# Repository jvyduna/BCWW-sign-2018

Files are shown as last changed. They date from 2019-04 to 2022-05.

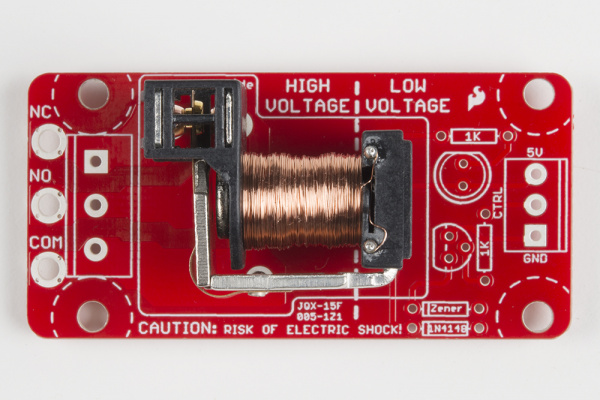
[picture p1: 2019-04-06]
Physical sign design/Microcontroller/RelayNaked.jpg

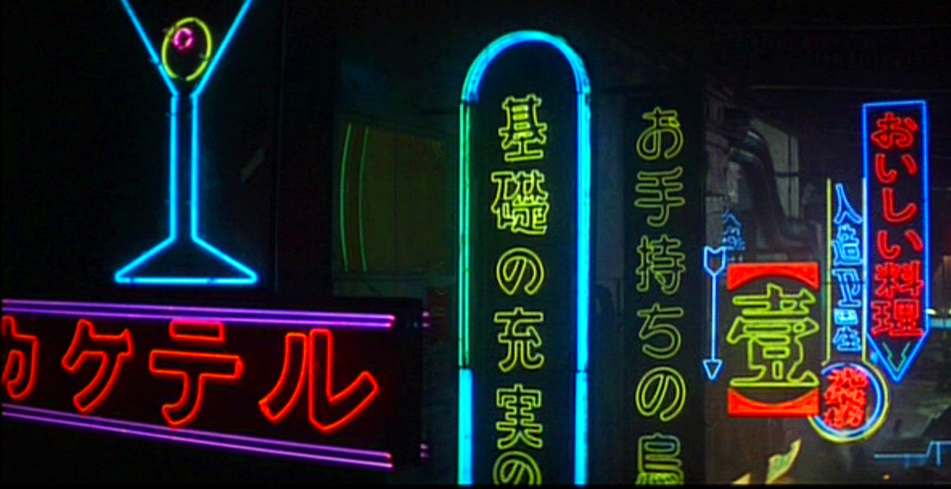
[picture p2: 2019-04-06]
Physical sign design/Inspiration board/Neon row.jpg

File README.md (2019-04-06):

# Bao Chicka Wow Wow blinking sign

BCWW Sign at dusk

[Video of sign at Burning Man 2018 and fab process](https://vimeo.com/292647048)

## Files

The contents of this repo mirror the structure of the Arduino project directory. Dependencies are included in the libraries/ folder. For the time-of-day mode switching timers to work, you'll need to copy the contents of this directory into your Arduino build location for libraries. That's usually just ```{your Arduino homedir}/libraries```.

## Hardware

Arduino Pro or Pro Mini (config included)
ATMega328P (5V, 16 MHz)

## Pinout

Documented in the code

All 5 signs are connectted in parallel on a 10-conductor ribbon cable.
One line controls the servo that changes the fourth sign from  WOW to NOW

## Physical sign design files

Design (Illustrator)

Modeling / CAD (Autodesk Inventor)

CNC GCode: Vector / ShopBot

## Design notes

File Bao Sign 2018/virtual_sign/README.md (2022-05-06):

Runs a virtual version of the sign in your terminal.

To build and run, run `build_and_run.sh`

If you want to see the debug logs, run `tail -F /tmp/virtual_sign.err`

To switch to Hot Bao Now mode, `touch /tmp/bao.touch`

To switch back, `rm /tmp/bao.touch`

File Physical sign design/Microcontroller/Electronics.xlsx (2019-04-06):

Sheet: BOM
Description | Need | Bought
Ribbon Cable | 50' | 100' | https://smile.amazon.com/Pc-Accessories-1-27mm-Connectors-Conductors/dp/B00JKE10UQ
Ribbon snap-on Fem | 6 | 50 | https://smile.amazon.com/gp/product/B00DE5CTMK/ref=ox_sc_act_title_1?smid=A64W1E1ZZHST0&psc=1
Ribbon male box header | 5 | 6 | https://www.sparkfun.com/products/8506
Protoboard |  |  | https://www.sparkfun.com/products/13268
NC Relay, Zener, Diode, 1KOhm, 293904 | 5 | 7 | https://cdn.sparkfun.com/datasheets/Components/General/SparkFun_Beefcake_Relay_Control_Kit_v20a.pdf
Servo for N/W | 1 | 1 | https://www.sparkfun.com/products/11965
5V 5A Power Supply - host in N/W
Arduino Pro Mini 5V

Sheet: Ribbon Pinout
 |  |  | Viewed from front of male connector
Pin | Function
1 | GND
2 | GND2 or SIGN1OUTLINE
3 | SIGN1 |  |  | (Relay)
4 | SIGN2
5 | SIGN3 |  |  | NOTCH
6 | SIGN4 | 9 | 7 | 5 | 3 | 1
7 | SIGN5 | 10 | 8 | 6 | 4 | 2
8 | SIGN4SERVO
9 | Vcc2 or SIGN5OUTLINE
10 | Vcc (from Sign4)
 |  |  |  | NOTCH
 |  | Vcc2 or SIGN5OUTLINE | SIGN5 | SIGN3 | SIGN1 | GND
 |  | Vcc (from Sign4) | SIGN4SERVO | SIGN4 | SIGN2 | GND2 or SIGN1OUTLINE

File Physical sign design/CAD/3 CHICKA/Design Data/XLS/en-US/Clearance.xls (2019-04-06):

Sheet: Ansi Unified Screw Threads
I | Sort Order -1
Fastener Type | Size | Shaft Diameters |  |  | Head Dimensions
 |  | Close | Normal | Loose | Diameter | Depth/Angle | Head Type
Flat Head Machine Screw (82) | #0 | 0.0635 | 0.07 | 0.073 | 0.119 | 82 | 2
Flat Head Machine Screw (82) | #1 | 0.076 | 0.081 | 0.089 | 0.146 | 82 | 2
Flat Head Machine Screw (82) | #2 | 0.089 | 0.096 | 0.1065 | 0.172 | 82 | 2
Flat Head Machine Screw (82) | #3 | 0.104 | 0.11 | 0.12 | 0.199 | 82 | 2
Flat Head Machine Screw (82) | #4 | 0.116 | 0.1285 | 0.136 | 0.225 | 82 | 2
Flat Head Machine Screw (82) | #5 | 0.1285 | 0.136 | 0.154 | 0.252 | 82 | 2
Flat Head Machine Screw (82) | #6 | 0.144 | 0.1495 | 0.1695 | 0.279 | 82 | 2
Flat Head Machine Screw (82) | #8 | 0.1695 | 0.177 | 0.1935 | 0.332 | 82 | 2
Flat Head Machine Screw (82) | #10 | 0.196 | 0.201 | 0.221 | 0.385 | 82 | 2
Flat Head Machine Screw (82) | #12 | 0.221 | 0.228 | 0.246 | 0.438 | 82 | 2
Flat Head Machine Screw (82) | 1/4 | 0.257 | 0.266 | 0.2812 | 0.507 | 82 | 2
Flat Head Machine Screw (82) | 5/16 | 0.323 | 0.332 | 0.3437 | 0.635 | 82 | 2
Flat Head Machine Screw (82) | 3/8 | 0.386 | 0.397 | 0.4062 | 0.762 | 82 | 2
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

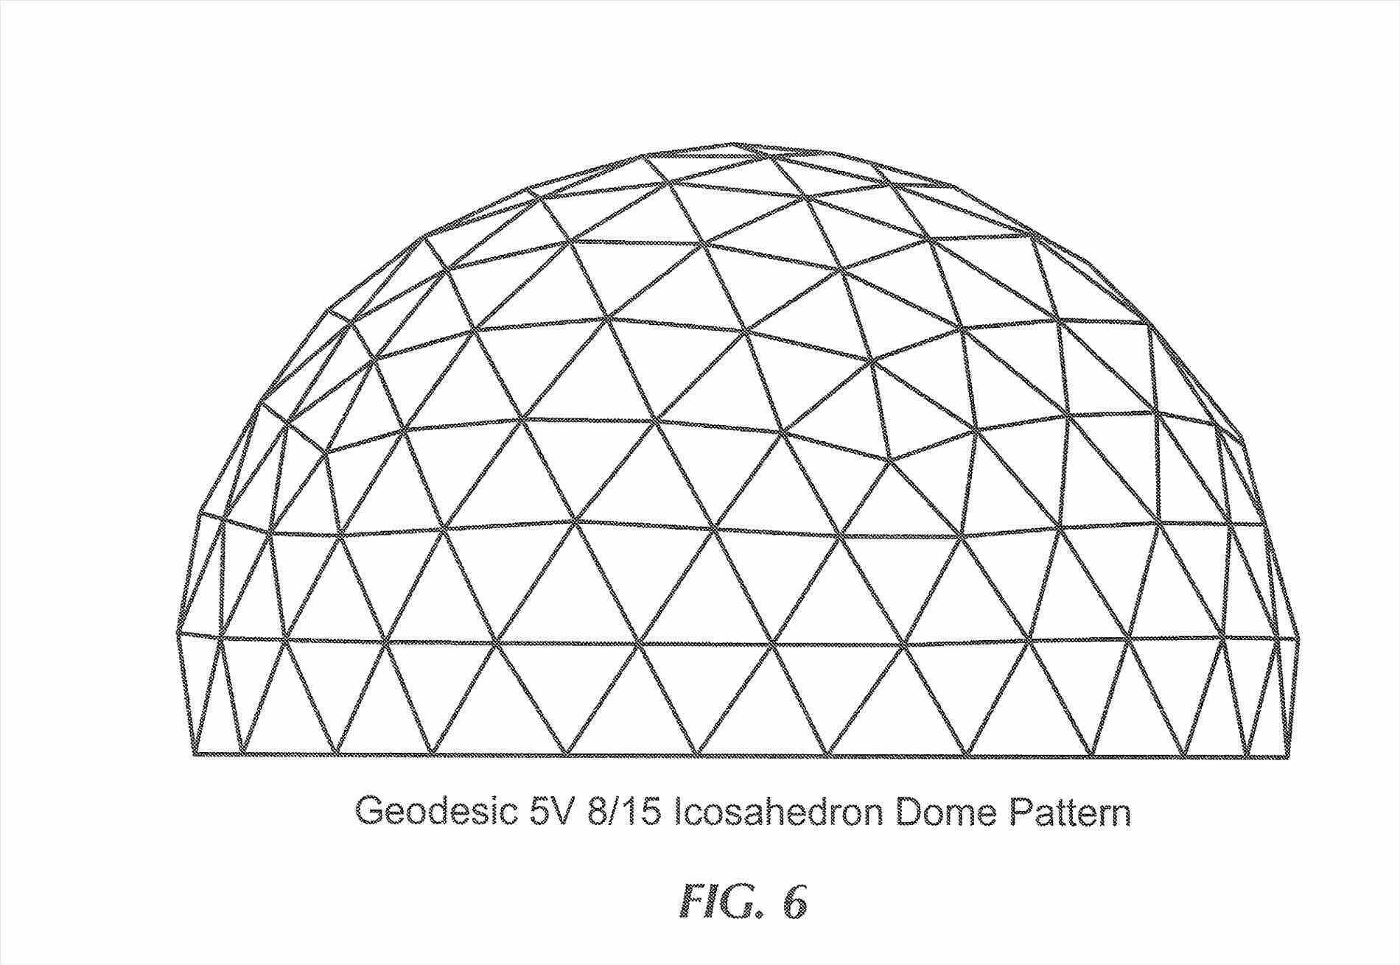
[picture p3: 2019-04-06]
Physical sign design/Assets/dome-drawing-the-in-architecturerhthoughtcocom-gallery-of-tejlgaard-u-jepsen-transform-a-temporary-rharchdailycom-gallery-geodesic-dome-drawing-of-tejlgaard-u-jepsen-trans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

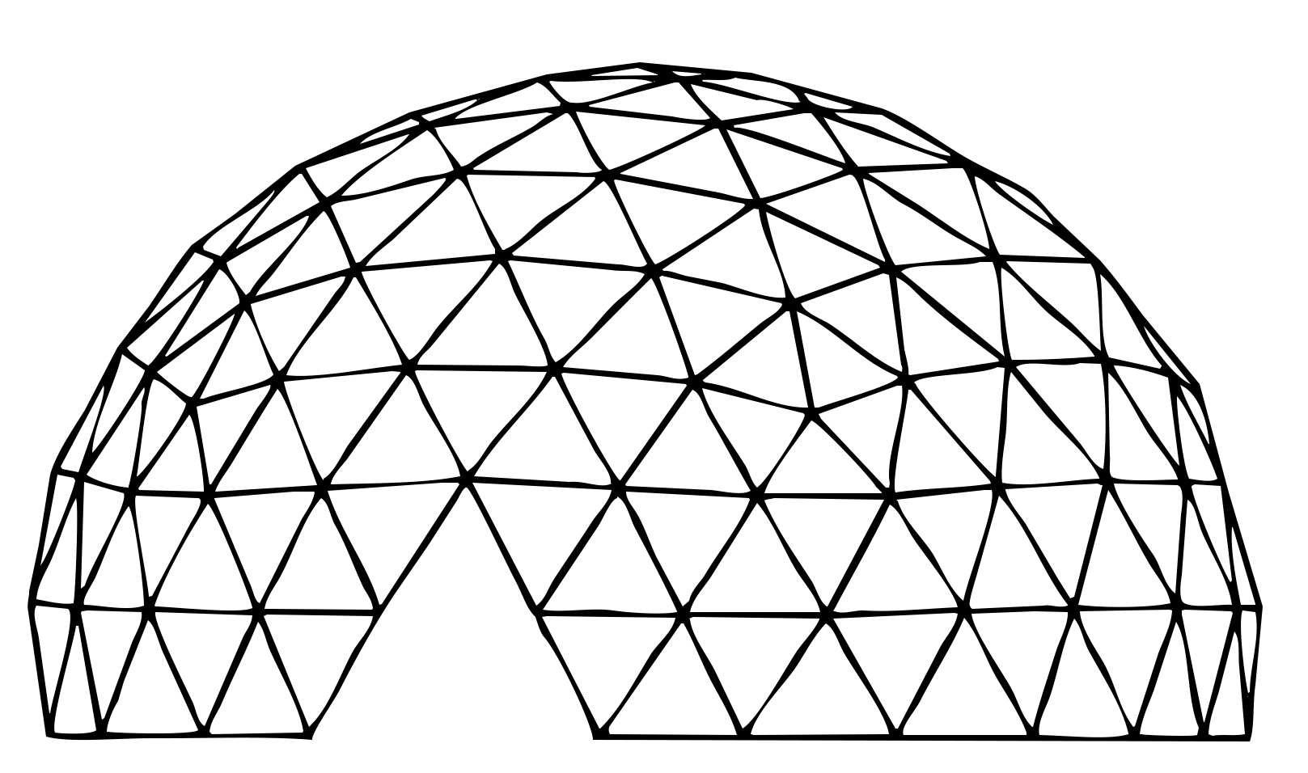
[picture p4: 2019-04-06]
Physical sign design/Assets/blackdome on tx.png

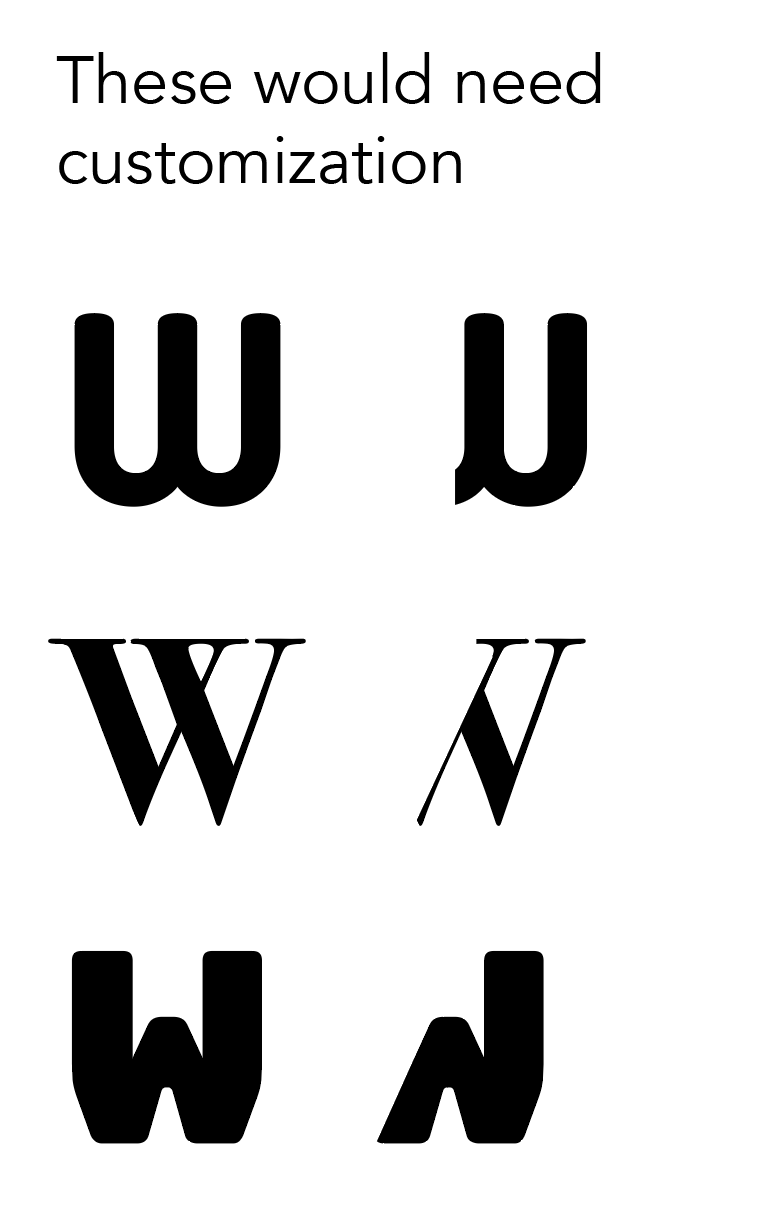
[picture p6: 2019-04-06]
Physical sign design/Prototypes/W-N not so much.png

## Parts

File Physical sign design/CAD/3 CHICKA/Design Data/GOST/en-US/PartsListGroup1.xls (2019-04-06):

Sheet: Лист 1
Инв. № подл |  |  |  | Подп. и дата | Взам. инв. № | Инв. № дубл. |  |  | Подп. и дата
Формат | Зона | Поз. | Обозначение |  |  |  | Наименование |  |  |  |  |  | Кол. на исполнение
 |  |  |  |  |  |  |  |  |  |  |  | Лит.
 |  |  |  |  |  |  |  |  |  |  |  | Код
 |  |  |  |  |  |  |  | Изм. | Лист | № докум | Подпись |  | Дата
 |  |  |  |  |  |  |  | Разраб.
 |  |  |  |  |  |  |  | Пров.
 |  |  |  |  |  |  |  | Н.контр
 |  |  |  |  |  |  |  | Утв.
 |  |  |  |  |  |  |  |  |  |  |  |  |  | Копировал

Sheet: Лист 2
Инв. № подл |  |  |  | Подп. и дата | Взам. инв. № | Инв. № дубл. |  |  | Подп. и дата
Формат | Зона | Поз. | Обозначение |  |  |  | Наименование |  |  |  |  | Кол. на исполнение
 |  |  |  |  |  |  |  | Изм. | Лист | № докум. | Подп. | Дата
 |  |  |  |  |  |  |  |  |  |  |  |  | Копировал
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

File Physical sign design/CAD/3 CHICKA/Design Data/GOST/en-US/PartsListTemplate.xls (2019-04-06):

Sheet: Лист 1
 | Формат | Зона |  | Поз. |  | Обозначение |  |  |  | Наименование |  |  |  | Кол. | Приме-чание
Подп. и дата
Инв. № дубл.
Взам. инв. №
Подп. и дата
 | Изм. |  | Лист |  | № докум |  | Подпись | Дата
Инв. № подл | Разраб. |  |  |  |  |  |  |  |  |  | Литера |  | Лист |  |  | Листов
 | Пров.
 | Н.контр
 | Утв.
 |  |  |  |  |  |  |  |  | Копировал |  |  | Формат А4

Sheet: Лист 2
 | Формат | Зона |  | Поз. |  | Обозначение |  |  |  | Наименование |  | Кол. | Приме-чание
Подп. и дата
Инв. № дубл.
Взам. инв. №
Подп. и дата
Инв. № подл
 | Изм. |  | Лист |  | № докум. |  | Подп. |  | Дата
 |  |  |  |  |  |  |  | Копировал |  |  | Формат А4
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

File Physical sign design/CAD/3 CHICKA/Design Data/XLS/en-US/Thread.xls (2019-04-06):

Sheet: ANSI Unified Screw Threads
I Q | ANSI Unified Screw Threads |  | Sort Order -1 |  | External |  |  |  |  |  |  | Internal
 |  |  |  |  |  | Major Dia |  | Pitch Dia |  | Minor Dia |  |  | Minor Dia |  | Pitch Dia |  | Major Dia |  | Tap Drill
Size | Size Suffix | Thread Designation | Custom Thread Designation | TPI | Class | Max | Min | Max | Min | Max | Min | Class | Min | Max | Min | Max | Min | Max | Basic
0.0118 |  | 30-318 UNM | 30-318 UNM | 318 | 2A | 0.0118 | 0.0112 | 0.0098 | 0.0092 | 0.0080 |  | 2B | 0.0085 | 0.0100 | 0.0098 | 0.0103 | 0.0120 |  | 0.0083
0.0138 |  | 35-282 UNM | 35-282 UNM | 282 | 2A | 0.0138 | 0.0131 | 0.0115 | 0.0109 | 0.0095 |  | 2B | 0.0101 | 0.0117 | 0.0115 | 0.0121 | 0.0140 |  | 0.0096
0.0157 |  | 40-254 UNM | 40-254 UNM | 254 | 2A | 0.0157 | 0.0150 | 0.0132 | 0.0126 | 0.0110 |  | 2B | 0.0117 | 0.0134 | 0.0132 | 0.0138 | 0.0160 |  | 0.0110
0.0177 |  | 45-254 UNM | 45-254 UNM | 254 | 2A | 0.0177 | 0.0170 | 0.0152 | 0.0145 | 0.0130 |  | 2B | 0.0136 | 0.0154 | 0.0152 | 0.0158 | 0.0180 |  | 0.0124
0.0197 |  | 50-203 UNM | 50-203 UNM | 203 | 2A | 0.0197 | 0.0189 | 0.0165 | 0.0158 | 0.0138 |  | 2B | 0.0146 | 0.0166 | 0.0165 | 0.0172 | 0.0200 |  | 0.0138
0.021 |  | 0000-160 NS | 0000-160 NS | 160 | 2A | 0.021 | 0.0195 | 0.0169 | 0.0158 | 0.0128 |  | 2B | 0.0169 | 0.0181 | 0.0169 | 0.0181 | 0.021
0.0217 |  | 55-203 UNM | 55-203 UNM | 203 | 2A | 0.0217 | 0.0208 | 0.0185 | 0.0178 | 0.0157 |  | 2B | 0.0165 | 0.0186 | 0.0185 | 0.0192 | 0.0220 |  | 0.0150
0.0236 |  | 60-169 UNM | 60-169 UNM | 169 | 2A | 0.0236 | 0.0227 | 0.0198 | 0.0190 | 0.0165 |  | 2B | 0.0175 | 0.0198 | 0.0198 | 0.0206 | 0.0241 |  | 0.0165

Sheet: Inch Tapping Threads
I Q X | Inch Tapping Threads |  | Sort Order - 5 |  | External |  |  |  |  |  |  | Internal
 |  |  |  |  |  | Major Dia |  | Pitch Dia |  | Minor Dia |  |  | Minor Dia |  | Pitch Dia |  | Major Dia |  | Tap Drill
Size | Size Suffix | Thread Designation | Custom Thread Designation | TPI | Class | Max | Min | Max | Min | Max | Min | Class | Min | Max | Min | Max | Min | Max | Basic
0.0600 |  | 0-48 | 0-48 | 48 | 2B | 0.0600 | 0.0540 | 0.0480 | 0.0435 | 0.0360 | 0.0330
0.0730 |  | 1-42 | 1-42 | 42 | 2B | 0.0750 | 0.0690 | 0.0620 | 0.0575 | 0.0490 | 0.0460
0.0860 |  | 2-32 | 2-32 | 32 | 2B | 0.0880 | 0.0820 | 0.0760 | 0.0710 | 0.0640 | 0.0600
0.0990 |  | 3-28 | 3-28 | 28 | 2B | 0.1010 | 0.0950 | 0.0880 | 0.0830 | 0.0750 | 0.0710
0.1120 |  | 4-24 | 4-24 | 24 | 2B | 0.1140 | 0.1080 | 0.1000 | 0.0950 | 0.0860 | 0.0820
0.1250 |  | 5-20 | 5-20 | 20 | 2B | 0.1300 | 0.1230 | 0.1120 | 0.1065 | 0.0940 | 0.0900
0.1380 |  | 6-20 | 6-20 | 20 | 2B | 0.1390 | 0.1320 | 0.1215 | 0.1155 | 0.1040 | 0.0990
0.1510 |  | 7-19 | 7-19 | 19 | 2B | 0.1540 | 0.1470 | 0.1345 | 0.1280 | 0.1150 | 0.1090
0.1640 |  | 8-18 | 8-18 | 18 | 2B | 0.1660 | 0.1590 | 0.1440 | 0.1375 | 0.1220 | 0.1160
0.1900 |  | 10-16 | 10-16 | 16 | 2B | 0.1890 | 0.1820 | 0.1650 | 0.1585 | 0.1410 | 0.1350
0.2160 |  | 12-14 | 12-14 | 14 | 2B | 0.2150 | 0.2080 | 0.1895 | 0.1825 | 0.1640 | 0.1570
0.2420 |  | 14-14 | 14-14 | 14 | 2B | 0.2410 | 0.2340 | 0.2130 | 0.2060 | 0.1850 | 0.1780
0.2500 |  | 1/4-14 | 1/4-14 | 14 | 2B | 0.2460 | 0.2370 | 0.2190 | 0.2110 | 0.1920 | 0.1850
0.3125 |  | 5/16-12 | 5/16-12 | 12 | 2B | 0.3150 | 0.3060 | 0.2795 | 0.2710 | 0.2440 | 0.2360
0.3750 |  | 3/8-12 | 3/8-12 | 12 | 2B | 0.3800 | 0.3710 | 0.3445 | 0.3350 | 0.3090 | 0.2990
0.4375 |  | 7/16-10 | 7/16-10 | 10 | 2B | 0.4400 | 0.4290 | 0.3995 | 0.3890 | 0.3590 | 0.3490
0.5000 |  | 1/2-10 | 1/2-10 | 10 | 2B | 0.5040 | 0.4930 | 0.4635 | 0.4530 | 0.4230 | 0.4130

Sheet: Metric Forming Screw Threads
M P X | Metric Forming Screw Threads |  | Sort Order - 6 |  | External |  |  |  |  |  |  | Internal
 |  |  |  |  |  | Major Dia |  | Pitch Dia |  | Minor Dia |  |  | Minor Dia |  | Pitch Dia |  | Major Dia |  | Tap Drill
Size | Size Suffix | Thread Designation | Custom Thread Designation | Pitch | Class | Max | Min | Max | Min | Max | Min | Class | Min | Max | Min | Max | Min | Max | Basic
1.5 |  | 1.5x0.5 | 1.5x0.5 | 0.5 | 6g | 1.520 | 1.380 | 1.215 | 1.110 | 0.910 | 0.840
1.5 |  | ST1.5x0.5 | ST1.5x0.5 | 0.5 | 6g | 1.520 | 1.380 | 1.215 | 1.110 | 0.910 | 0.840
1.9 |  | 1.9x0.6 | 1.9x0.6 | 0.6 | 6g | 1.900 | 1.760 | 1.570 | 1.465 | 1.240 | 1.170
1.9 |  | ST1.9x0.6 | ST1.9x0.6 | 0.6 | 6g | 1.900 | 1.760 | 1.570 | 1.465 | 1.240 | 1.170
2.2 |  | 2.2x0.8 | 2.2x0.8 | 0.8 | 6g | 2.240 | 2.100 | 1.935 | 1.810 | 1.630 | 1.520
2.2 |  | ST2.2x0.8 | ST2.2x0.8 | 0.8 | 6g | 2.240 | 2.100 | 1.935 | 1.810 | 1.630 | 1.520
2.6 |  | 2.6x0.9 | 2.6x0.9 | 0.9 | 6g | 2.570 | 2.430 | 2.235 | 2.115 | 1.900 | 1.800
2.6 |  | ST2.6x0.9 | ST2.6x0.9 | 0.9 | 6g | 2.570 | 2.430 | 2.235 | 2.115 | 1.900 | 1.800
2.9 |  | 2.9x1 | 2.9x1 | 1 | 6g | 2.900 | 2.760 | 2.540 | 2.420 | 2.180 | 2.080
2.9 |  | 2.9x1.1 | 2.9x1.1 | 1.1 | 6g | 2.900 | 2.760 | 2.540 | 2.420 | 2.180 | 2.080
2.9 |  | ST2.9x1.1 | ST2.9x1.1 | 1.1 | 6g | 2.900 | 2.760 | 2.540 | 2.420 | 2.180 | 2.080
2.9 |  | 2.9x1.3 | 2.9x1.3 | 1.3 | 6g | 2.900 | 2.720 | 2.540 | 2.355 | 1.890 | 1.700
2.9 |  | 2.9x1.4 | 2.9x1.4 | 1.4 | 6g | 2.900 | 2.720 | 2.340 | 2.175 | 1.780 | 1.630
3.3 |  | 3.3x1.3 | 3.3x1.3 | 1.3 | 6g | 3.300 | 3.120 | 2.795 | 2.665 | 2.290 | 2.210
3.3 |  | ST3.3x1.3 | ST3.3x1.3 | 1.3 | 6g | 3.300 | 3.120 | 2.795 | 2.665 | 2.290 | 2.210
3.5 |  | 3.5x1.3 | 3.5x1.3 | 1.3 | 6g | 3.530 | 3.350 | 3.085 | 2.930 | 2.640 | 2.510
3.5 |  | ST3.5x1.3 | ST3.5x1.3 | 1.3 | 6g | 3.530 | 3.350 | 3.085 | 2.930 | 2.640 | 2.510
3.5 |  | 3.5x1.6 | 3.5x1.6 | 1.6 | 6g | 3.530 | 3.350 | 2.920 | 2.755 | 2.310 | 2.160
3.5 |  | 3.5x3.2 | 3.5x3.2 | 3.2 | 6g | 3.530 | 3.310 | 2.800 | 2.600 | 2.070 | 1.890
3.9 |  | 3.9x1.3 | 3.9x1.3 | 1.3 | 6g | 3.910 | 3.730 | 3.415 | 3.250 | 2.920 | 2.770
3.9 |  | ST3.9x1.3 | ST3.9x1.3 | 1.3 | 6g | 3.910 | 3.730 | 3.415 | 3.250 | 2.920 | 2.770
3.9 |  | 3.9x1.6 | 3.9x1.6 | 1.6 | 6g | 3.910 | 3.730 | 3.300 | 3.135 | 2.690 | 2.540
3.9 |  | 3.9x3.2 | 3.9x3.2 | 3.2 | 6g | 3.910 | 3.690 | 3.180 | 2.980 | 2.450 | 2.270
4.2 |  | 4.2x1.4 | 4.2x1.4 | 1.4 | 6g | 4.220 | 4.040 | 3.660 | 3.495 | 3.100 | 2.950
4.2 |  | ST4.2x1.4 | ST4.2x1.4 | 1.4 | 6g | 4.220 | 4.040 | 3.660 | 3.495 | 3.100 | 2.950
4.2 |  | 4.2x1.6 | 4.2x1.6 | 1.6 | 6g | 4.220 | 4.040 | 3.610 | 3.445 | 3.000 | 2.850
4.2 |  | 4.2x3.2 | 4.2x3.2 | 3.2 | 6g | 4.220 | 4.000 | 3.380 | 3.180 | 2.540 | 2.360
4.8 |  | 4.8x1.6 | 4.8x1.6 | 1.6 | 6g | 4.800 | 4.620 | 4.190 | 4.025 | 3.580 | 3.430
4.8 |  | ST4.8x1.6 | ST4.8x1.6 | 1.6 | 6g | 4.800 | 4.620 | 4.190 | 4.025 | 3.580 | 3.430
4.8 |  | 4.8x1.8 | 4.8x1.8 | 1.8 | 6g | 4.800 | 4.620 | 4.065 | 3.885 | 3.330 | 3.150
4.8 |  | 4.8x3.2 | 4.8x3.2 | 3.2 | 6g | 4.800 | 4.580 | 3.960 | 3.760 | 3.120 | 2.940
5.5 |  | 5.5x1.8 | 5.5x1.8 | 1.8 | 6g | 5.460 | 5.280 | 4.815 | 4.635 | 4.170 | 3.990
5.5 |  | ST5.5x1.8 | ST5.5x1.8 | 1.8 | 6g | 5.460 | 5.280 | 4.815 | 4.635 | 4.170 | 3.990
6.3 |  | 6.3x1.8 | 6.3x1.8 | 1.8 | 6g | 6.250 | 6.030 | 5.565 | 5.365 | 4.880 | 4.700
6.3 |  | ST6.3x1.8 | ST6.3x1.8 | 1.8 | 6g | 6.250 | 6.030 | 5.565 | 5.365 | 4.880 | 4.700
8.0 |  | 8x2.1 | 8x2.1 | 2.1 | 6g | 8.000 | 7.780 | 7.100 | 6.885 | 6.200 | 5.990
8.0 |  | ST8x2.1 | ST8x2.1 | 2.1 | 6g | 8.000 | 7.780 | 7.100 | 6.885 | 6.200 | 5.990
9.5 |  | 9.5x2.1 | 9.5x2.1 | 2.1 | 6g | 9.650 | 9.430 | 8.750 | 8.510 | 7.850 | 7.590
9.5 |  | ST9.5x2.1 | ST9.5x2.1 | 2.1 | 6g | 9.650 | 9.430 | 8.750 | 8.510 | 7.850 | 7.590

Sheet: ISO Pipe Threads
M Q | ISO Pipe Threads |  | Sort Order - 9 |  | External |  |  |  |  |  |  | Internal
 |  |  |  |  |  | Major Dia |  | Pitch Dia |  | Minor Dia |  |  | Minor Dia |  | Pitch Dia |  | Major Dia |  | Tap Drill
Size | Size Suffix | Thread Designation | Custom Thread Designation | TPI | Class | Max | Min | Max | Min | Max | Min | Class | Min | Max | Min | Max | Min | Max | Basic
7.723 |  | G7.723x0.907 | G 1/16 | 28 | A | 7.723 | 7.509 | 7.142 | 7.035 | 6.561 |  |  | 6.561 | 6.834 | 7.142 | 7.249 | 7.723 |  | 1.5875
7.723 |  | G7.723x0.907 | G 1/16 | 28 | B | 7.723 | 7.509 | 7.142 | 6.928 | 6.561
9.728 |  | G9.728x0.907 | G 1/8 | 28 | A | 9.728 | 9.514 | 9.147 | 9.040 | 8.566 |  |  | 8.566 | 8.848 | 9.147 | 9.254 | 9.728 |  | 3.1750
9.728 |  | G9.728x0.907 | G 1/8 | 28 | B | 9.728 | 9.514 | 9.147 | 8.933 | 8.566
13.157 |  | G13.157x1.337 | G 1/4 | 19 | A | 13.157 | 12.907 | 12.301 | 12.176 | 11.445 |  |  | 11.445 | 11.89 | 12.301 | 12.426 | 13.157 |  | 6.3500
13.157 |  | G13.157x1.337 | G 1/4 | 19 | B | 13.157 | 12.907 | 12.301 | 12.051 | 11.445
16.662 |  | G16.662x1.337 | G 3/8 | 19 | A | 16.662 | 16.412 | 15.806 | 15.681 | 14.950 |  |  | 14.95 | 15.395 | 15.806 | 15.931 | 16.662 |  | 9.5250
16.662 |  | G16.662x1.337 | G 3/8 | 19 | B | 16.662 | 16.412 | 15.806 | 15.556 | 14.950
20.955 |  | G20.955x1.814 | G 1/2 | 14 | A | 20.955 | 20.671 | 19.793 | 19.651 | 18.631 |  |  | 18.631 | 19.172 | 19.793 | 19.935 | 20.955 |  | 12.7000
20.955 |  | G20.955x1.814 | G 1/2 | 14 | B | 20.955 | 20.671 | 19.793 | 19.509 | 18.631
22.911 |  | G22.911x1.814 | G 5/8 | 14 | A | 22.911 | 22.627 | 21.749 | 21.607 | 20.587 |  |  | 20.587 | 21.128 | 21.749 | 21.891 | 22.911
22.911 |  | G22.911x1.814 | G 5/8 | 14 | B | 22.911 | 22.627 | 21.749 | 21.465 | 20.587
26.441 |  | G26.441x1.814 | G 3/4 | 14 | A | 26.441 | 26.157 | 25.279 | 25.137 | 24.117 |  |  | 24.117 | 24.658 | 25.279 | 25.421 | 26.441 |  | 15.8750
26.441 |  | G26.441x1.814 | G 3/4 | 14 | B | 26.441 | 26.157 | 25.279 | 24.995 | 24.117
30.201 |  | G30.201x1.814 | G 7/8 | 14 | A | 30.201 | 29.917 | 29.039 | 28.897 | 27.877 |  |  | 27.877 | 28.418 | 29.039 | 29.181 | 30.201 |  | 22.2250
30.201 |  | G30.201x1.814 | G 7/8 | 14 | B | 30.201 | 29.917 | 29.039 | 28.755 | 27.877
33.249 |  | G33.249x2.309 | G 1 | 11 | A | 33.249 | 32.889 | 31.770 | 31.590 | 30.291 |  |  | 30.291 | 30.931 | 31.77 | 31.95 | 33.249 |  | 25.4000
33.249 |  | G33.249x2.309 | G 1 | 11 | B | 33.249 | 32.889 | 31.770 | 31.410 | 30.291
37.897 |  | G37.897x2.309 | G 1 1/8 | 11 | A | 37.897 | 37.537 | 36.418 | 36.238 | 34.939 |  |  | 34.939 | 35.579 | 36.418 | 36.598 | 37.897 |  | 28.5750
37.897 |  | G37.897x2.309 | G 1 1/8 | 11 | B | 37.897 | 37.537 | 36.418 | 36.058 | 34.939
41.910 |  | G41.91x2.309 | G 1 1/4 | 11 | A | 41.910 | 41.550 | 40.431 | 40.251 | 38.952 |  |  | 38.952 | 39.592 | 40.431 | 40.611 | 41.910 |  | 31.7500
41.910 |  | G41.91x2.309 | G 1 1/4 | 11 | B | 41.910 | 41.550 | 40.431 | 40.071 | 38.952
47.803 |  | G47.803x2.309 | G 1 1/2 | 11 | A | 47.803 | 47.443 | 46.324 | 46.144 | 44.845 |  |  | 44.845 | 45.485 | 46.324 | 46.504 | 47.803 |  | 38.1000
47.803 |  | G47.803x2.309 | G 1 1/2 | 11 | B | 47.803 | 47.443 | 46.324 | 45.964 | 44.845
53.746 |  | G53.746x2.309 | G 1 3/4 | 11 | A | 53.746 | 53.386 | 52.267 | 52.087 | 50.788 |  |  | 50.788 | 51.428 | 52.267 | 52.447 | 53.746 |  | 44.4500
53.746 |  | G53.746x2.309 | G 1 3/4 | 11 | B | 53.746 | 53.386 | 52.267 | 51.907 | 50.788
59.614 |  | G59.614x2.309 | G 2 | 11 | A | 59.614 | 59.254 | 58.135 | 57.955 | 56.656 |  |  | 56.656 | 57.296 | 58.135 | 58.315 | 59.614 |  | 50.8000
59.614 |  | G59.614x2.309 | G 2 | 11 | B | 59.614 | 59.254 | 58.135 | 57.775 | 56.656
65.710 |  | G65.71x2.309 | G 2 1/4 | 11 | A | 65.710 | 65.276 | 64.231 | 64.014 | 62.752 |  |  | 62.752 | 63.392 | 64.231 | 64.448 | 65.710 |  | 57.1500
65.710 |  | G65.71x2.309 | G 2 1/4 | 11 | B | 65.710 | 65.276 | 64.231 | 63.797 | 62.752
75.184 |  | G75.184x2.309 | G 2 1/2 | 11 | A | 75.184 | 74.750 | 73.705 | 73.488 | 72.226 |  |  | 72.226 | 72.866 | 73.705 | 73.922 | 75.184
75.184 |  | G75.184x2.309 | G 2 1/2 | 11 | B | 75.184 | 74.750 | 73.705 | 73.271 | 72.226
81.534 |  | G81.534x2.309 | G 2 3/4 | 11 | A | 81.534 | 81.100 | 80.055 | 79.838 | 78.576 |  |  | 78.576 | 79.216 | 80.055 | 80.272 | 81.534 |  | 69.8500
81.534 |  | G81.534x2.309 | G 2 3/4 | 11 | B | 81.534 | 81.100 | 80.055 | 79.621 | 78.576
87.884 |  | G87.884x2.309 | G 3 | 11 | A | 87.884 | 87.450 | 86.405 | 86.188 | 84.926 |  |  | 84.926 | 85.566 | 86.405 | 86.622 | 87.884 |  | 76.2000
87.884 |  | G87.884x2.309 | G 3 | 11 | B | 87.884 | 87.450 | 86.405 | 85.971 | 84.926
100.330 |  | G100.33x2.309 | G 3 1/2 | 11 | A | 100.330 | 99.896 | 98.851 | 98.634 | 97.372 |  |  | 97.372 | 98.012 | 98.851 | 99.068 | 100.330 |  | 88.9000
100.330 |  | G100.33x2.309 | G 3 1/2 | 11 | B | 100.330 | 99.896 | 98.851 | 98.417 | 97.372
113.030 |  | G113.03x2.309 | G 4 | 11 | A | 113.030 | 112.596 | 111.551 | 111.334 | 110.072 |  |  | 110.072 | 110.712 | 111.551 | 111.768 | 113.030 |  | 101.6000
113.030 |  | G113.03x2.309 | G 4 | 11 | B | 113.030 | 112.596 | 111.551 | 111.117 | 110.072
125.730 |  | G125.73x2.309 | G 4 1/2 | 11 | A | 125.730 | 125.296 | 124.251 | 124.034 | 122.772 |  |  | 122.772 | 123.412 | 124.251 | 124.468 | 125.730 |  | 114.3000
125.730 |  | G125.73x2.309 | G 4 1/2 | 11 | B | 125.730 | 125.296 | 124.251 | 123.817 | 122.772
138.430 |  | G138.43x2.309 | G 5 | 11 | A | 138.430 | 137.996 | 136.951 | 136.734 | 135.472 |  |  | 135.472 | 136.112 | 136.951 | 137.168 | 138.430 |  | 127.0000
138.430 |  | G138.43x2.309 | G 5 | 11 | B | 138.430 | 137.996 | 136.951 | 136.517 | 135.472
151.130 |  | G151.13x2.309 | G 5 1/2 | 11 | A | 151.130 | 150.696 | 149.651 | 149.434 | 148.172 |  |  | 148.172 | 148.812 | 149.651 | 149.868 | 151.130 |  | 139.7000
151.130 |  | G151.13x2.309 | G 5 1/2 | 11 | B | 151.130 | 150.696 | 149.651 | 149.217 | 148.172
163.830 |  | G163.83x2.309 | G 6 | 11 | A | 163.830 | 163.396 | 162.351 | 162.134 | 160.872 |  |  | 160.872 | 161.512 | 162.351 | 162.568 | 163.830 |  | 152.4000
163.830 |  | G163.83x2.309 | G 6 | 11 | B | 163.830 | 163.396 | 162.351 | 161.917 | 160.872

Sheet: JIS Pipe Threads
M Q | JIS Pipe Threads |  | Sort Order -12 |  | External |  |  |  |  |  |  | Internal
 |  |  |  |  |  | Major Dia |  | Pitch Dia |  | Minor Dia |  |  | Minor Dia |  | Pitch Dia |  | Major Dia |  | Tap Drill
Size | Size Suffix | Thread Designation | Custom Thread Designation | TPI | Class | Max | Min | Max | Min | Max | Min | Class | Min | Max | Min | Max | Min | Max | Basic
7.723 |  | G7.723x0.907 | G 1/16 | 28 | A | 7.723 | 7.509 | 7.142 | 7.035 | 6.561 |  |  | 6.561 | 6.834 | 7.142 | 7.249 | 7.723 |  | 1.5875
7.723 |  | G7.723x0.907 | G 1/16 | 28 | B | 7.723 | 7.509 | 7.142 | 6.928 | 6.561
9.728 |  | G9.728x0.907 | G 1/8 | 28 | A | 9.728 | 9.514 | 9.147 | 9.040 | 8.566 |  |  | 8.566 | 8.848 | 9.147 | 9.254 | 9.728 |  | 3.1750
9.728 |  | G9.728x0.907 | G 1/8 | 28 | B | 9.728 | 9.514 | 9.147 | 8.933 | 8.566
13.157 |  | G13.157x1.337 | G 1/4 | 19 | A | 13.157 | 12.907 | 12.301 | 12.176 | 11.445 |  |  | 11.445 | 11.89 | 12.301 | 12.426 | 13.157 |  | 6.3500
13.157 |  | G13.157x1.337 | G 1/4 | 19 | B | 13.157 | 12.907 | 12.301 | 12.051 | 11.445
16.662 |  | G16.662x1.337 | G 3/8 | 19 | A | 16.662 | 16.412 | 15.806 | 15.681 | 14.950 |  |  | 14.95 | 15.395 | 15.806 | 15.931 | 16.662 |  | 9.5250
16.662 |  | G16.662x1.337 | G 3/8 | 19 | B | 16.662 | 16.412 | 15.806 | 15.556 | 14.950
20.955 |  | G20.955x1.814 | G 1/2 | 14 | A | 20.955 | 20.671 | 19.793 | 19.651 | 18.631 |  |  | 18.631 | 19.172 | 19.793 | 19.935 | 20.955 |  | 12.7000
20.955 |  | G20.955x1.814 | G 1/2 | 14 | B | 20.955 | 20.671 | 19.793 | 19.509 | 18.631
22.911 |  | G22.911x1.814 | G 5/8 | 14 | A | 22.911 | 22.627 | 21.749 | 21.607 | 20.587 |  |  | 20.587 | 21.128 | 21.749 | 21.891 | 22.911
22.911 |  | G22.911x1.814 | G 5/8 | 14 | B | 22.911 | 22.627 | 21.749 | 21.465 | 20.587
26.441 |  | G26.441x1.814 | G 3/4 | 14 | A | 26.441 | 26.157 | 25.279 | 25.137 | 24.117 |  |  | 24.117 | 24.658 | 25.279 | 25.421 | 26.441 |  | 15.8750
26.441 |  | G26.441x1.814 | G 3/4 | 14 | B | 26.441 | 26.157 | 25.279 | 24.995 | 24.117
30.201 |  | G30.201x1.814 | G 7/8 | 14 | A | 30.201 | 29.917 | 29.039 | 28.897 | 27.877 |  |  | 27.877 | 28.418 | 29.039 | 29.181 | 30.201 |  | 22.2250
30.201 |  | G30.201x1.814 | G 7/8 | 14 | B | 30.201 | 29.917 | 29.039 | 28.755 | 27.877
33.249 |  | G33.249x2.309 | G 1 | 11 | A | 33.249 | 32.889 | 31.770 | 31.590 | 30.291 |  |  | 30.291 | 30.931 | 31.77 | 31.95 | 33.249 |  | 25.4000
33.249 |  | G33.249x2.309 | G 1 | 11 | B | 33.249 | 32.889 | 31.770 | 31.410 | 30.291
37.897 |  | G37.897x2.309 | G 1 1/8 | 11 | A | 37.897 | 37.537 | 36.418 | 36.238 | 34.939 |  |  | 34.939 | 35.579 | 36.418 | 36.598 | 37.897 |  | 28.5750
37.897 |  | G37.897x2.309 | G 1 1/8 | 11 | B | 37.897 | 37.537 | 36.418 | 36.058 | 34.939
41.910 |  | G41.91x2.309 | G 1 1/4 | 11 | A | 41.910 | 41.550 | 40.431 | 40.251 | 38.952 |  |  | 38.952 | 39.592 | 40.431 | 40.611 | 41.910 |  | 31.7500
41.910 |  | G41.91x2.309 | G 1 1/4 | 11 | B | 41.910 | 41.550 | 40.431 | 40.071 | 38.952
47.803 |  | G47.803x2.309 | G 1 1/2 | 11 | A | 47.803 | 47.443 | 46.324 | 46.144 | 44.845 |  |  | 44.845 | 45.485 | 46.324 | 46.504 | 47.803 |  | 38.1000
47.803 |  | G47.803x2.309 | G 1 1/2 | 11 | B | 47.803 | 47.443 | 46.324 | 45.964 | 44.845
53.746 |  | G53.746x2.309 | G 1 3/4 | 11 | A | 53.746 | 53.386 | 52.267 | 52.087 | 50.788 |  |  | 50.788 | 51.428 | 52.267 | 52.447 | 53.746 |  | 44.4500
53.746 |  | G53.746x2.309 | G 1 3/4 | 11 | B | 53.746 | 53.386 | 52.267 | 51.907 | 50.788
59.614 |  | G59.614x2.309 | G 2 | 11 | A | 59.614 | 59.254 | 58.135 | 57.955 | 56.656 |  |  | 56.656 | 57.296 | 58.135 | 58.315 | 59.614 |  | 50.8000
59.614 |  | G59.614x2.309 | G 2 | 11 | B | 59.614 | 59.254 | 58.135 | 57.775 | 56.656
65.710 |  | G65.71x2.309 | G 2 1/4 | 11 | A | 65.710 | 65.276 | 64.231 | 64.014 | 62.752 |  |  | 62.752 | 63.392 | 64.231 | 64.448 | 65.710 |  | 57.1500
65.710 |  | G65.71x2.309 | G 2 1/4 | 11 | B | 65.710 | 65.276 | 64.231 | 63.797 | 62.752
75.184 |  | G75.184x2.309 | G 2 1/2 | 11 | A | 75.184 | 74.750 | 73.705 | 73.488 | 72.226 |  |  | 72.226 | 72.866 | 73.705 | 73.922 | 75.184
75.184 |  | G75.184x2.309 | G 2 1/2 | 11 | B | 75.184 | 74.750 | 73.705 | 73.271 | 72.226
81.534 |  | G81.534x2.309 | G 2 3/4 | 11 | A | 81.534 | 81.100 | 80.055 | 79.838 | 78.576 |  |  | 78.576 | 79.216 | 80.055 | 80.272 | 81.534 |  | 69.8500
81.534 |  | G81.534x2.309 | G 2 3/4 | 11 | B | 81.534 | 81.100 | 80.055 | 79.621 | 78.576
87.884 |  | G87.884x2.309 | G 3 | 11 | A | 87.884 | 87.450 | 86.405 | 86.188 | 84.926 |  |  | 84.926 | 85.566 | 86.405 | 86.622 | 87.884 |  | 76.2000
87.884 |  | G87.884x2.309 | G 3 | 11 | B | 87.884 | 87.450 | 86.405 | 85.971 | 84.926
100.330 |  | G100.33x2.309 | G 3 1/2 | 11 | A | 100.330 | 99.896 | 98.851 | 98.634 | 97.372 |  |  | 97.372 | 98.012 | 98.851 | 99.068 | 100.330 |  | 88.9000
100.330 |  | G100.33x2.309 | G 3 1/2 | 11 | B | 100.330 | 99.896 | 98.851 | 98.417 | 97.372
113.030 |  | G113.03x2.309 | G 4 | 11 | A | 113.030 | 112.596 | 111.551 | 111.334 | 110.072 |  |  | 110.072 | 110.712 | 111.551 | 111.768 | 113.030 |  | 101.6000
113.030 |  | G113.03x2.309 | G 4 | 11 | B | 113.030 | 112.596 | 111.551 | 111.117 | 110.072
125.730 |  | G125.73x2.309 | G 4 1/2 | 11 | A | 125.730 | 125.296 | 124.251 | 124.034 | 122.772 |  |  | 122.772 | 123.412 | 124.251 | 124.468 | 125.730 |  | 114.3000
125.730 |  | G125.73x2.309 | G 4 1/2 | 11 | B | 125.730 | 125.296 | 124.251 | 123.817 | 122.772
138.430 |  | G138.43x2.309 | G 5 | 11 | A | 138.430 | 137.996 | 136.951 | 136.734 | 135.472 |  |  | 135.472 | 136.112 | 136.951 | 137.168 | 138.430 |  | 127.0000
138.430 |  | G138.43x2.309 | G 5 | 11 | B | 138.430 | 137.996 | 136.951 | 136.517 | 135.472
151.130 |  | G151.13x2.309 | G 5 1/2 | 11 | A | 151.130 | 150.696 | 149.651 | 149.434 | 148.172 |  |  | 148.172 | 148.812 | 149.651 | 149.868 | 151.130 |  | 139.7000
151.130 |  | G151.13x2.309 | G 5 1/2 | 11 | B | 151.130 | 150.696 | 149.651 | 149.217 | 148.172
163.830 |  | G163.83x2.309 | G 6 | 11 | A | 163.830 | 163.396 | 162.351 | 162.134 | 160.872 |  |  | 160.872 | 161.512 | 162.351 | 162.568 | 163.830 |  | 152.4000
163.830 |  | G163.83x2.309 | G 6 | 11 | B | 163.830 | 163.396 | 162.351 | 161.917 | 160.872

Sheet: DIN Pipe Threads
M Q | DIN Pipe Threads |  | Sort Order - 18 |  | External |  |  |  |  |  |  | Internal
 |  |  |  |  |  | Major Dia |  | Pitch Dia |  | Minor Dia |  |  | Minor Dia |  | Pitch Dia |  | Major Dia |  | Tap Drill
Size | Size Suffix | Thread Designation | Custom Thread Designation | TPI | Class | Max | Min | Max | Min | Max | Min | Class | Min | Max | Min | Max | Min | Max | Basic
7.723 |  | G7.723x0.907 | G 1/16 | 28 | A | 7.723 | 7.509 | 7.142 | 7.035 | 6.561 |  |  | 6.561 | 6.834 | 7.142 | 7.249 | 7.723 |  | 1.5875
7.723 |  | G7.723x0.907 | G 1/16 | 28 | B | 7.723 | 7.509 | 7.142 | 6.928 | 6.561
9.728 |  | G9.728x0.907 | G 1/8 | 28 | A | 9.728 | 9.514 | 9.147 | 9.040 | 8.566 |  |  | 8.566 | 8.848 | 9.147 | 9.254 | 9.728 |  | 3.1750
9.728 |  | G9.728x0.907 | G 1/8 | 28 | B | 9.728 | 9.514 | 9.147 | 8.933 | 8.566
13.157 |  | G13.157x1.337 | G 1/4 | 19 | A | 13.157 | 12.907 | 12.301 | 12.176 | 11.445 |  |  | 11.445 | 11.89 | 12.301 | 12.426 | 13.157 |  | 6.3500
13.157 |  | G13.157x1.337 | G 1/4 | 19 | B | 13.157 | 12.907 | 12.301 | 12.051 | 11.445
16.662 |  | G16.662x1.337 | G 3/8 | 19 | A | 16.662 | 16.412 | 15.806 | 15.681 | 14.950 |  |  | 14.95 | 15.395 | 15.806 | 15.931 | 16.662 |  | 9.5250
16.662 |  | G16.662x1.337 | G 3/8 | 19 | B | 16.662 | 16.412 | 15.806 | 15.556 | 14.950
20.955 |  | G20.955x1.814 | G 1/2 | 14 | A | 20.955 | 20.671 | 19.793 | 19.651 | 18.631 |  |  | 18.631 | 19.172 | 19.793 | 19.935 | 20.955 |  | 12.7000
20.955 |  | G20.955x1.814 | G 1/2 | 14 | B | 20.955 | 20.671 | 19.793 | 19.509 | 18.631
22.911 |  | G22.911x1.814 | G 5/8 | 14 | A | 22.911 | 22.627 | 21.749 | 21.607 | 20.587 |  |  | 20.587 | 21.128 | 21.749 | 21.891 | 22.911
22.911 |  | G22.911x1.814 | G 5/8 | 14 | B | 22.911 | 22.627 | 21.749 | 21.465 | 20.587
26.441 |  | G26.441x1.814 | G 3/4 | 14 | A | 26.441 | 26.157 | 25.279 | 25.137 | 24.117 |  |  | 24.117 | 24.658 | 25.279 | 25.421 | 26.441 |  | 15.8750
26.441 |  | G26.441x1.814 | G 3/4 | 14 | B | 26.441 | 26.157 | 25.279 | 24.995 | 24.117
30.201 |  | G30.201x1.814 | G 7/8 | 14 | A | 30.201 | 29.917 | 29.039 | 28.897 | 27.877 |  |  | 27.877 | 28.418 | 29.039 | 29.181 | 30.201 |  | 22.2250
30.201 |  | G30.201x1.814 | G 7/8 | 14 | B | 30.201 | 29.917 | 29.039 | 28.755 | 27.877
33.249 |  | G33.249x2.309 | G 1 | 11 | A | 33.249 | 32.889 | 31.770 | 31.590 | 30.291 |  |  | 30.291 | 30.931 | 31.77 | 31.95 | 33.249 |  | 25.4000
33.249 |  | G33.249x2.309 | G 1 | 11 | B | 33.249 | 32.889 | 31.770 | 31.410 | 30.291
37.897 |  | G37.897x2.309 | G 1 1/8 | 11 | A | 37.897 | 37.537 | 36.418 | 36.238 | 34.939 |  |  | 34.939 | 35.579 | 36.418 | 36.598 | 37.897 |  | 28.5750
37.897 |  | G37.897x2.309 | G 1 1/8 | 11 | B | 37.897 | 37.537 | 36.418 | 36.058 | 34.939
41.910 |  | G41.91x2.309 | G 1 1/4 | 11 | A | 41.910 | 41.550 | 40.431 | 40.251 | 38.952 |  |  | 38.952 | 39.592 | 40.431 | 40.611 | 41.910 |  | 31.7500
41.910 |  | G41.91x2.309 | G 1 1/4 | 11 | B | 41.910 | 41.550 | 40.431 | 40.071 | 38.952
47.803 |  | G47.803x2.309 | G 1 1/2 | 11 | A | 47.803 | 47.443 | 46.324 | 46.144 | 44.845 |  |  | 44.845 | 45.485 | 46.324 | 46.504 | 47.803 |  | 38.1000
47.803 |  | G47.803x2.309 | G 1 1/2 | 11 | B | 47.803 | 47.443 | 46.324 | 45.964 | 44.845
53.746 |  | G53.746x2.309 | G 1 3/4 | 11 | A | 53.746 | 53.386 | 52.267 | 52.087 | 50.788 |  |  | 50.788 | 51.428 | 52.267 | 52.447 | 53.746 |  | 44.4500
53.746 |  | G53.746x2.309 | G 1 3/4 | 11 | B | 53.746 | 53.386 | 52.267 | 51.907 | 50.788
59.614 |  | G59.614x2.309 | G 2 | 11 | A | 59.614 | 59.254 | 58.135 | 57.955 | 56.656 |  |  | 56.656 | 57.296 | 58.135 | 58.315 | 59.614 |  | 50.8000
59.614 |  | G59.614x2.309 | G 2 | 11 | B | 59.614 | 59.254 | 58.135 | 57.775 | 56.656
65.710 |  | G65.71x2.309 | G 2 1/4 | 11 | A | 65.710 | 65.276 | 64.231 | 64.014 | 62.752 |  |  | 62.752 | 63.392 | 64.231 | 64.448 | 65.710 |  | 57.1500
65.710 |  | G65.71x2.309 | G 2 1/4 | 11 | B | 65.710 | 65.276 | 64.231 | 63.797 | 62.752
75.184 |  | G75.184x2.309 | G 2 1/2 | 11 | A | 75.184 | 74.750 | 73.705 | 73.488 | 72.226 |  |  | 72.226 | 72.866 | 73.705 | 73.922 | 75.184
75.184 |  | G75.184x2.309 | G 2 1/2 | 11 | B | 75.184 | 74.750 | 73.705 | 73.271 | 72.226
81.534 |  | G81.534x2.309 | G 2 3/4 | 11 | A | 81.534 | 81.100 | 80.055 | 79.838 | 78.576 |  |  | 78.576 | 79.216 | 80.055 | 80.272 | 81.534 |  | 69.8500
81.534 |  | G81.534x2.309 | G 2 3/4 | 11 | B | 81.534 | 81.100 | 80.055 | 79.621 | 78.576
87.884 |  | G87.884x2.309 | G 3 | 11 | A | 87.884 | 87.450 | 86.405 | 86.188 | 84.926 |  |  | 84.926 | 85.566 | 86.405 | 86.622 | 87.884 |  | 76.2000
87.884 |  | G87.884x2.309 | G 3 | 11 | B | 87.884 | 87.450 | 86.405 | 85.971 | 84.926
100.330 |  | G100.33x2.309 | G 3 1/2 | 11 | A | 100.330 | 99.896 | 98.851 | 98.634 | 97.372 |  |  | 97.372 | 98.012 | 98.851 | 99.068 | 100.330 |  | 88.9000
100.330 |  | G100.33x2.309 | G 3 1/2 | 11 | B | 100.330 | 99.896 | 98.851 | 98.417 | 97.372
113.030 |  | G113.03x2.309 | G 4 | 11 | A | 113.030 | 112.596 | 111.551 | 111.334 | 110.072 |  |  | 110.072 | 110.712 | 111.551 | 111.768 | 113.030 |  | 101.6000
113.030 |  | G113.03x2.309 | G 4 | 11 | B | 113.030 | 112.596 | 111.551 | 111.117 | 110.072
125.730 |  | G125.73x2.309 | G 4 1/2 | 11 | A | 125.730 | 125.296 | 124.251 | 124.034 | 122.772 |  |  | 122.772 | 123.412 | 124.251 | 124.468 | 125.730 |  | 114.3000
125.730 |  | G125.73x2.309 | G 4 1/2 | 11 | B | 125.730 | 125.296 | 124.251 | 123.817 | 122.772
138.430 |  | G138.43x2.309 | G 5 | 11 | A | 138.430 | 137.996 | 136.951 | 136.734 | 135.472 |  |  | 135.472 | 136.112 | 136.951 | 137.168 | 138.430 |  | 127.0000
138.430 |  | G138.43x2.309 | G 5 | 11 | B | 138.430 | 137.996 | 136.951 | 136.517 | 135.472
151.130 |  | G151.13x2.309 | G 5 1/2 | 11 | A | 151.130 | 150.696 | 149.651 | 149.434 | 148.172 |  |  | 148.172 | 148.812 | 149.651 | 149.868 | 151.130 |  | 139.7000
151.130 |  | G151.13x2.309 | G 5 1/2 | 11 | B | 151.130 | 150.696 | 149.651 | 149.217 | 148.172
163.830 |  | G163.83x2.309 | G 6 | 11 | A | 163.830 | 163.396 | 162.351 | 162.134 | 160.872 |  |  | 160.872 | 161.512 | 162.351 | 162.568 | 163.830 |  | 152.4000
163.830 |  | G163.83x2.309 | G 6 | 11 | B | 163.830 | 163.396 | 162.351 | 161.917 | 160.872

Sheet: BSP Pipe Threads
M Q | BSP Pipe Threads |  | Sort Order - 19 |  | External |  |  |  |  |  |  | Internal
 |  |  |  |  |  | Major Dia |  | Pitch Dia |  | Minor Dia |  |  | Minor Dia |  | Pitch Dia |  | Major Dia |  | Tap Drill
Size | Size Suffix | Thread Designation | Custom Thread Designation | TPI | Class | Max | Min | Max | Min | Max | Min | Class | Min | Max | Min | Max | Min | Max | Basic
1/16 |  | G 1/16-28 | G 1/16-28 | 28 | A | 7.723 | 7.509 | 7.142 | 7.035 | 6.561 |  |  | 6.561 | 6.834 | 7.142 | 7.249 | 7.723 |  | 6.6000
1/16 |  | G 1/16-28 | G 1/16-28 | 28 | B | 7.723 | 7.509 | 7.142 | 7.035 | 6.561
1/8 |  | G 1/8-28 | G 1/8-28 | 28 | A | 9.728 | 9.514 | 9.147 | 9.040 | 8.566 |  |  | 8.566 | 8.848 | 9.147 | 9.254 | 9.728 |  | 8.7300
1/8 |  | G 1/8-28 | G 1/8-28 | 28 | B | 9.728 | 9.514 | 9.147 | 9.040 | 8.566
1/4 |  | G 1/4-19 | G 1/4-19 | 19 | A | 13.157 | 12.907 | 12.301 | 12.176 | 11.445 |  |  | 11.445 | 11.89 | 12.301 | 12.426 | 13.157 |  | 11.8000
1/4 |  | G 1/4-19 | G 1/4-19 | 19 | B | 13.157 | 12.907 | 12.301 | 12.176 | 11.445
3/8 |  | G 3/8-19 | G 3/8-19 | 19 | A | 16.662 | 16.412 | 15.806 | 15.681 | 14.950 |  |  | 14.95 | 15.395 | 15.806 | 15.931 | 16.662 |  | 15.2500
3/8 |  | G 3/8-19 | G 3/8-19 | 19 | B | 16.662 | 16.412 | 15.806 | 15.681 | 14.950
1/2 |  | G 1/2-14 | G 1/2-14 | 14 | A | 20.955 | 20.671 | 19.793 | 19.651 | 18.631 |  |  | 18.631 | 19.172 | 19.793 | 19.935 | 20.955 |  | 19.0500
1/2 |  | G 1/2-14 | G 1/2-14 | 14 | B | 20.955 | 20.671 | 19.793 | 19.651 | 18.631
5/8 |  | G 5/8-14 | G 5/8-14 | 14 | A | 22.911 | 22.627 | 21.749 | 21.607 | 20.587 |  |  | 20.587 | 21.128 | 21.749 | 21.891 | 22.911 |  | 21.0000
5/8 |  | G 5/8-14 | G 5/8-14 | 14 | B | 22.911 | 22.627 | 21.749 | 21.607 | 20.587
3/4 |  | G 3/4-14 | G 3/4-14 | 14 | A | 26.441 | 26.157 | 25.279 | 25.137 | 24.117 |  |  | 24.117 | 24.658 | 25.279 | 25.421 | 26.441 |  | 24.5000
3/4 |  | G 3/4-14 | G 3/4-14 | 14 | B | 26.441 | 26.157 | 25.279 | 25.137 | 24.117
7/8 |  | G 7/8-14 | G 7/8-14 | 14 | A | 30.201 | 29.917 | 29.039 | 28.897 | 27.877 |  |  | 27.877 | 28.418 | 29.039 | 29.181 | 30.201 |  | 28.2500
7/8 |  | G 7/8-14 | G 7/8-14 | 14 | B | 30.201 | 29.917 | 29.039 | 28.897 | 27.877
1 |  | G 1-11 | G 1-11 | 11 | A | 33.249 | 32.889 | 31.770 | 31.590 | 30.291 |  |  | 30.291 | 30.931 | 31.77 | 31.95 | 33.249 |  | 30.7500
1 |  | G 1-11 | G 1-11 | 11 | B | 33.249 | 32.889 | 31.770 | 31.590 | 30.291
1 1/4 |  | G 1 1/4-11 | G 1 1/4-11 | 11 | A | 41.910 | 41.550 | 40.431 | 40.251 | 38.952 |  |  | 38.952 | 39.592 | 40.431 | 40.611 | 41.910 |  | 39.5000
1 1/4 |  | G 1 1/4-11 | G 1 1/4-11 | 11 | B | 41.910 | 41.550 | 40.431 | 40.251 | 38.952
1 1/2 |  | G 1 1/2-11 | G 1 1/2-11 | 11 | A | 47.803 | 47.443 | 46.324 | 46.144 | 44.845 |  |  | 44.845 | 45.485 | 46.324 | 46.504 | 47.803 |  | 45.5000
1 1/2 |  | G 1 1/2-11 | G 1 1/2-11 | 11 | B | 47.803 | 47.443 | 46.324 | 46.144 | 44.845
1 3/4 |  | G 1 3/4-11 | G 1 3/4-11 | 11 | A | 53.746 | 53.386 | 52.267 | 52.087 | 50.788 |  |  | 50.788 | 51.428 | 52.267 | 52.447 | 53.746 |  | 51.0000
1 3/4 |  | G 1 3/4-11 | G 1 3/4-11 | 11 | B | 53.746 | 53.386 | 52.267 | 52.087 | 50.788
2 |  | G 2-11 | G 2-11 | 11 | A | 59.614 | 59.254 | 58.135 | 57.955 | 56.656 |  |  | 56.656 | 57.296 | 58.135 | 58.315 | 59.614 |  | 57.0000
2 |  | G 2-11 | G 2-11 | 11 | B | 59.614 | 59.254 | 58.135 | 57.955 | 56.656
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

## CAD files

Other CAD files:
Physical sign design/CAD/1 HOT/Thermo.dxf
Physical sign design/CAD/3 CHICKA/Templates/English/ANSI (in).dwg
Physical sign design/CAD/3 CHICKA/Templates/Metric/ISO.dwg
Physical sign design/CAD/3 CHICKA/Templates/Standard.dwg
Physical sign design/CAD/4 NWOW/Templates/English/ANSI (in).dwg
Physical sign design/CAD/4 NWOW/Templates/Metric/DIN.dwg
Physical sign design/CAD/4 NWOW/Templates/Standard.dwg
Physical sign design/CAD/5 WOW!/Exclaim point.dxf
Physical sign design/CAD/3 CHICKA/Templates/English/am_ansi.dwg
Physical sign design/CAD/3 CHICKA/Templates/Metric/GB.dwg
Physical sign design/CAD/4 NWOW/Templates/English/am_ansi.dwg
Physical sign design/CAD/4 NWOW/Templates/Metric/am_din.dwg
Physical sign design/CAD/3 CHICKA/Templates/Metric/BSI.dwg
Physical sign design/CAD/4 NWOW/Templates/Metric/ISO.dwg
Physical sign design/CAD/3 CHICKA/Templates/Metric/GOST.dwg
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

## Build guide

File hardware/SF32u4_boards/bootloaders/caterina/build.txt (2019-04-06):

make clean
make PID=0x9209 F_CPU=16000000
copy Caterina.hex Caterina-wiflyin.hex
make clean
make PID=0x9207 F_CPU=8000000
copy Caterina.hex Caterina-lilypadusb.hex
make clean
make PID=0x9205 F_CPU=16000000
copy Caterina.hex Caterina-promicro16.hex
make clean
make PID=0x9203 F_CPU=8000000
copy Caterina.hex Caterina-promicro8.hex 
make clean
make PID=0x2B74 F_CPU=16000000
copy Caterina.hex Caterina-makey.hex
make clean
make PID=0xF100 F_CPU=8000000
copy Caterina.hex Caterina-fio.hex
make clean
make PID=0x920B F_CPU=16000000
copy Caterina.hex Caterina-minibench.hex

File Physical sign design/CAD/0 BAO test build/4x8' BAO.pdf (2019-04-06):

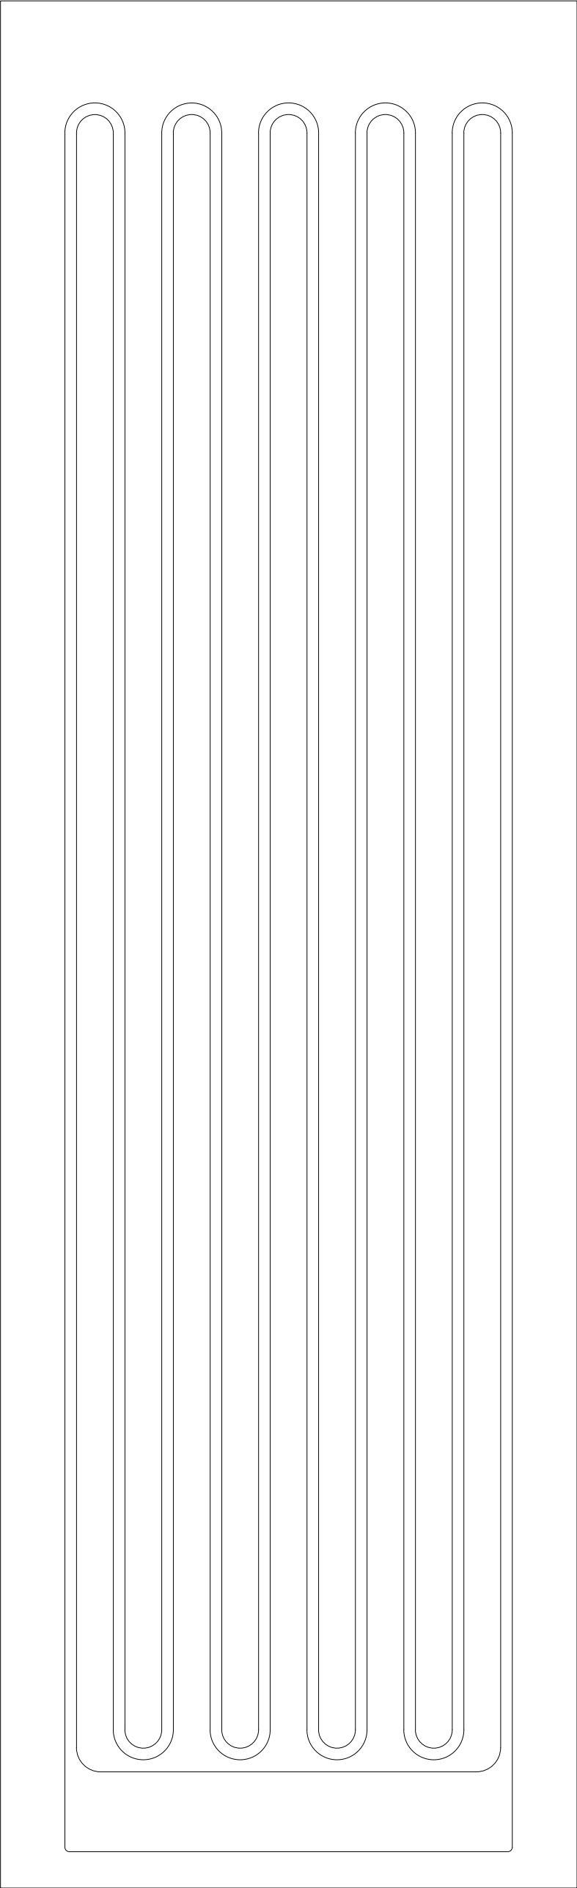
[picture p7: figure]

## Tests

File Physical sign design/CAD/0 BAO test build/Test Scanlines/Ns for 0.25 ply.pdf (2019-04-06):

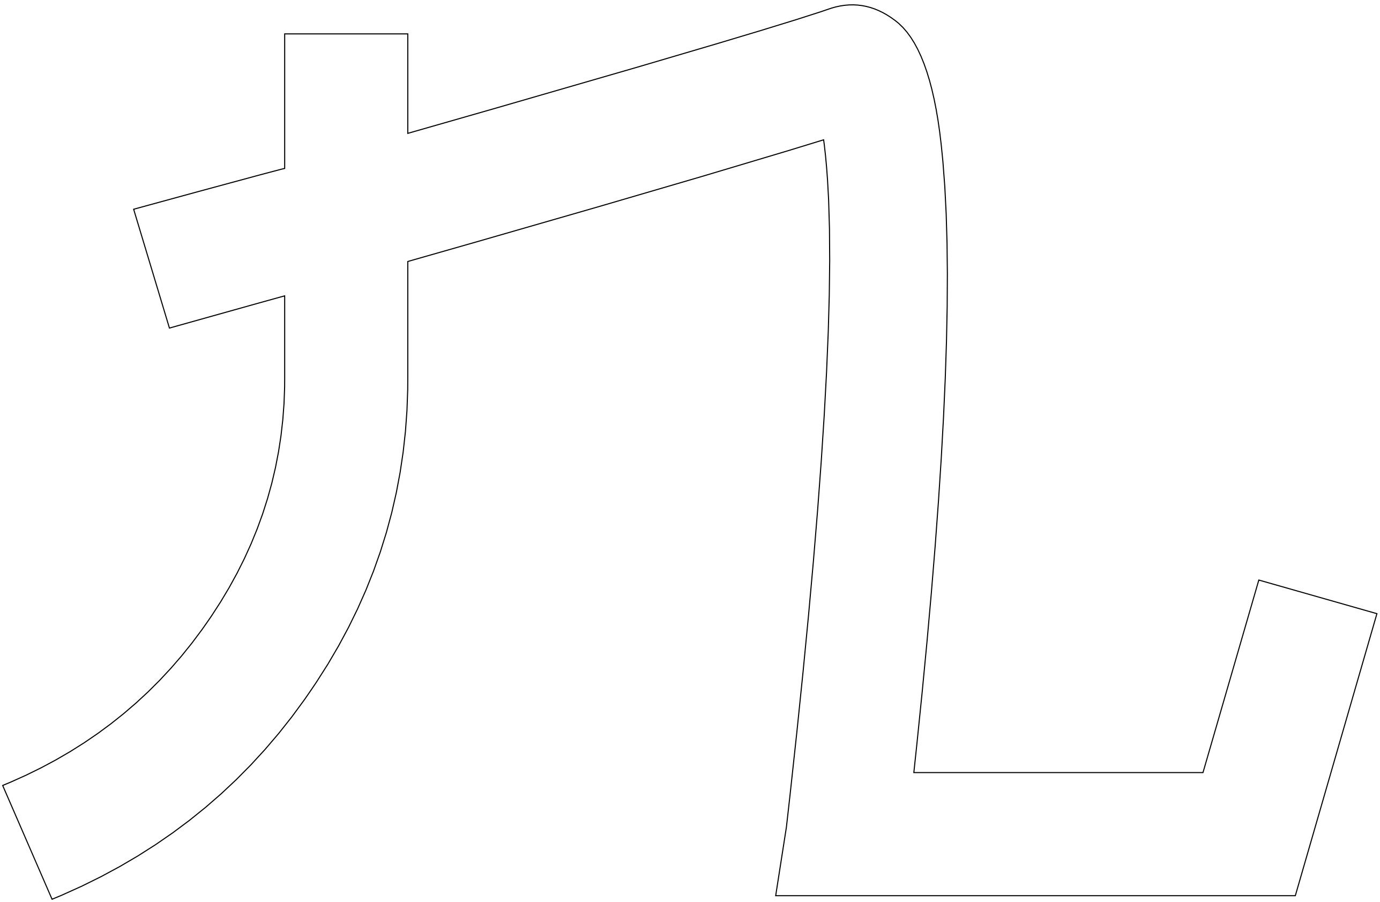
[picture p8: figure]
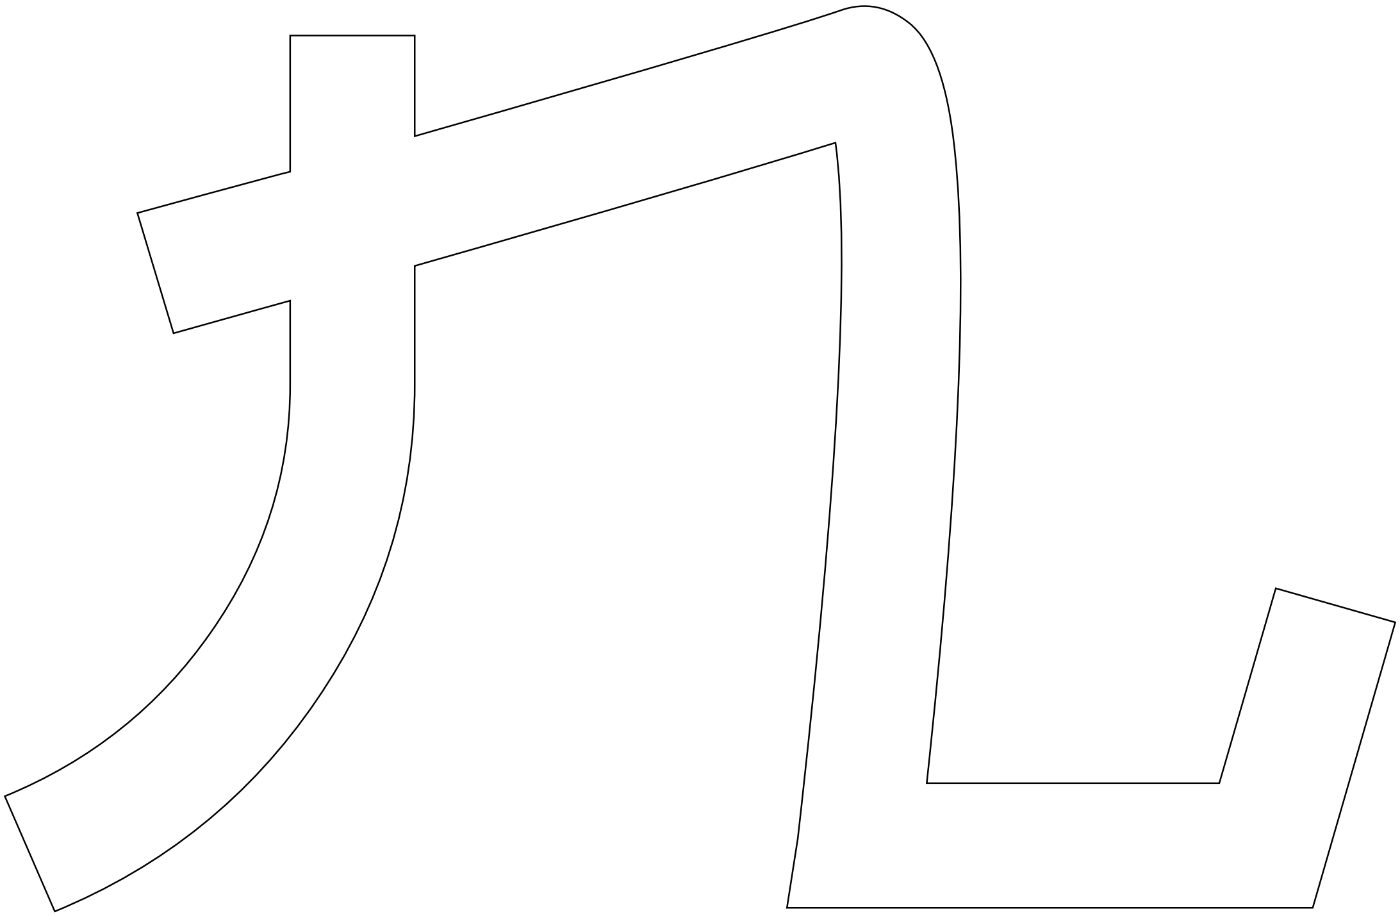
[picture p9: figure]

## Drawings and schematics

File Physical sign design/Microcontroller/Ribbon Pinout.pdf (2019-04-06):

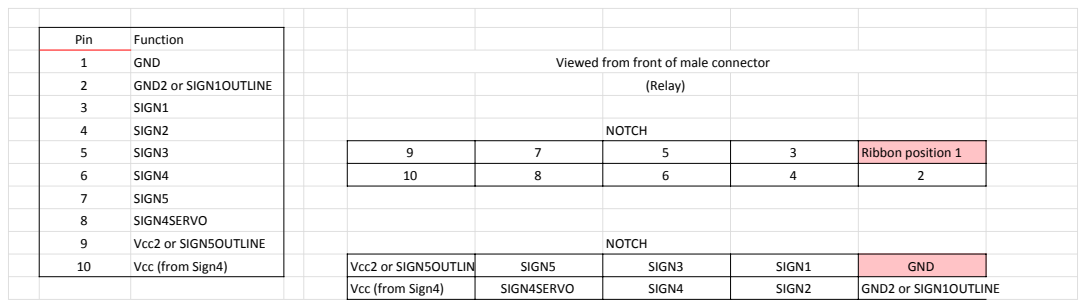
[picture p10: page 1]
Pin; Function; GND; Viewed from front of male connector; GND2 or SIGN1OUTLINE; (Relay); SIGN1; SIGN2; NOTCH; SIGN3; Ribbon position 1; SIGN4; SIGN5; SIGN4SERVO; Vcc2 or SIGN5OUTLINE; Vcc (from Sign4)

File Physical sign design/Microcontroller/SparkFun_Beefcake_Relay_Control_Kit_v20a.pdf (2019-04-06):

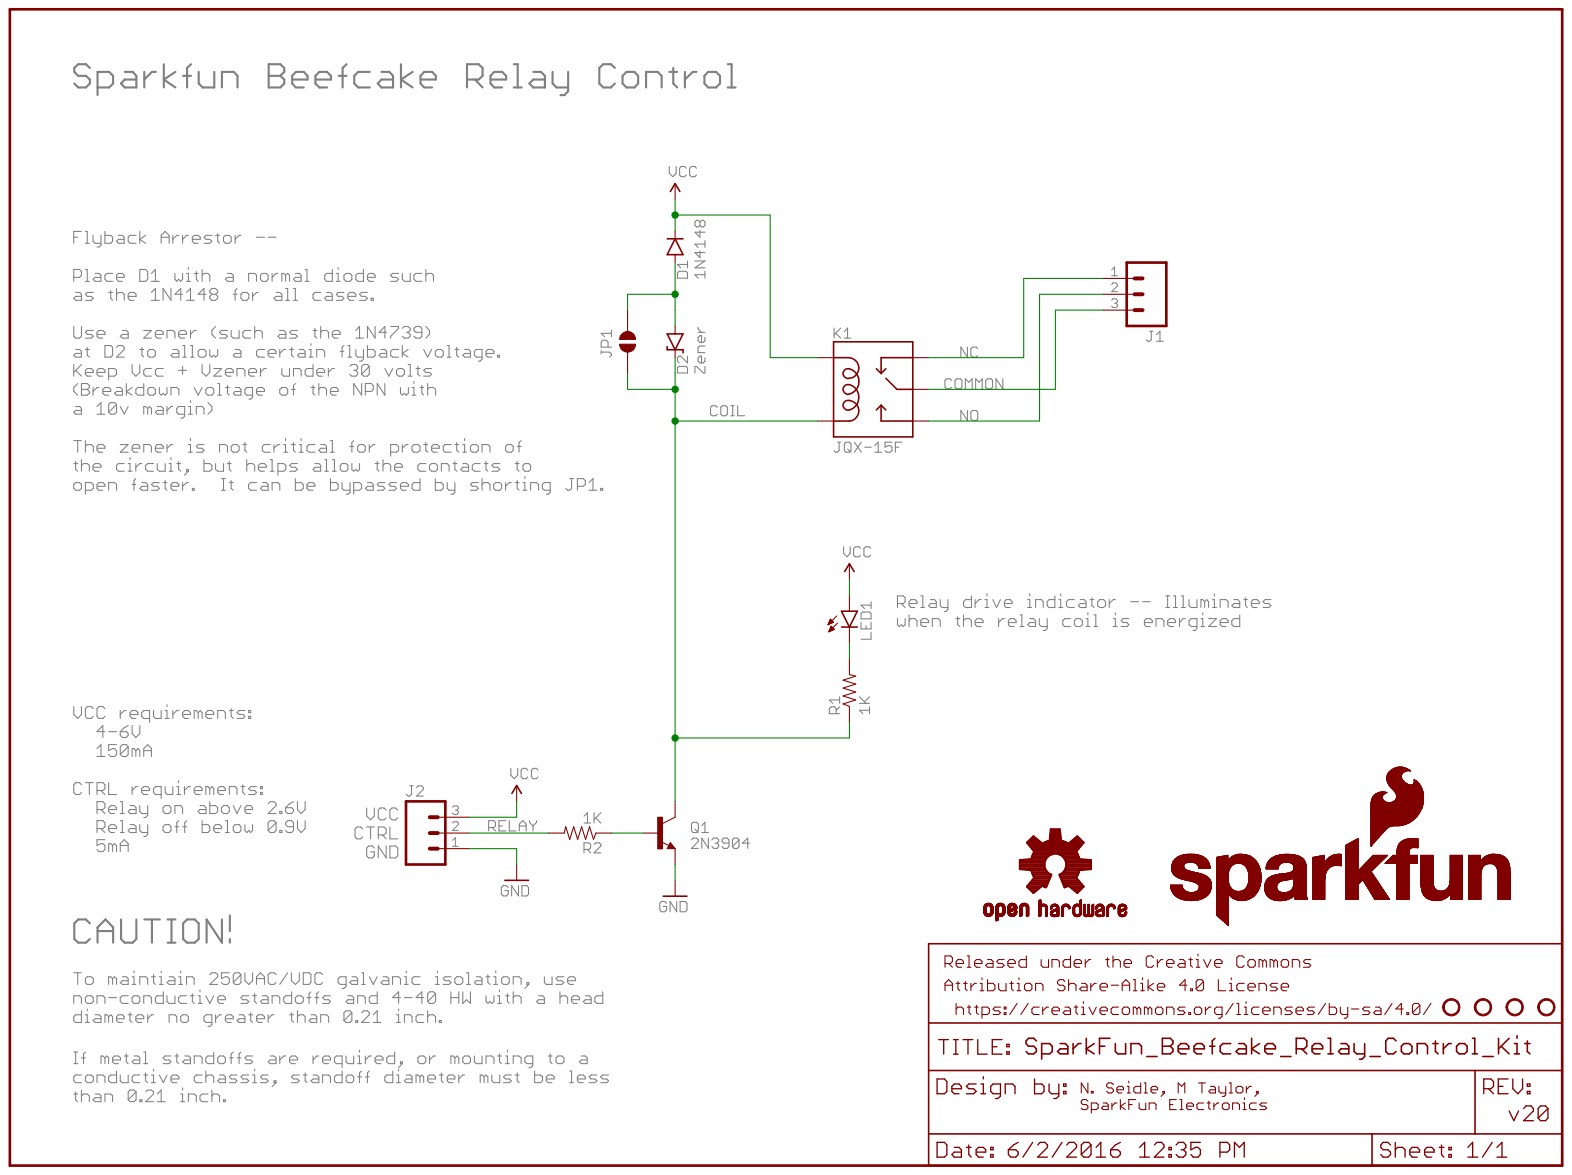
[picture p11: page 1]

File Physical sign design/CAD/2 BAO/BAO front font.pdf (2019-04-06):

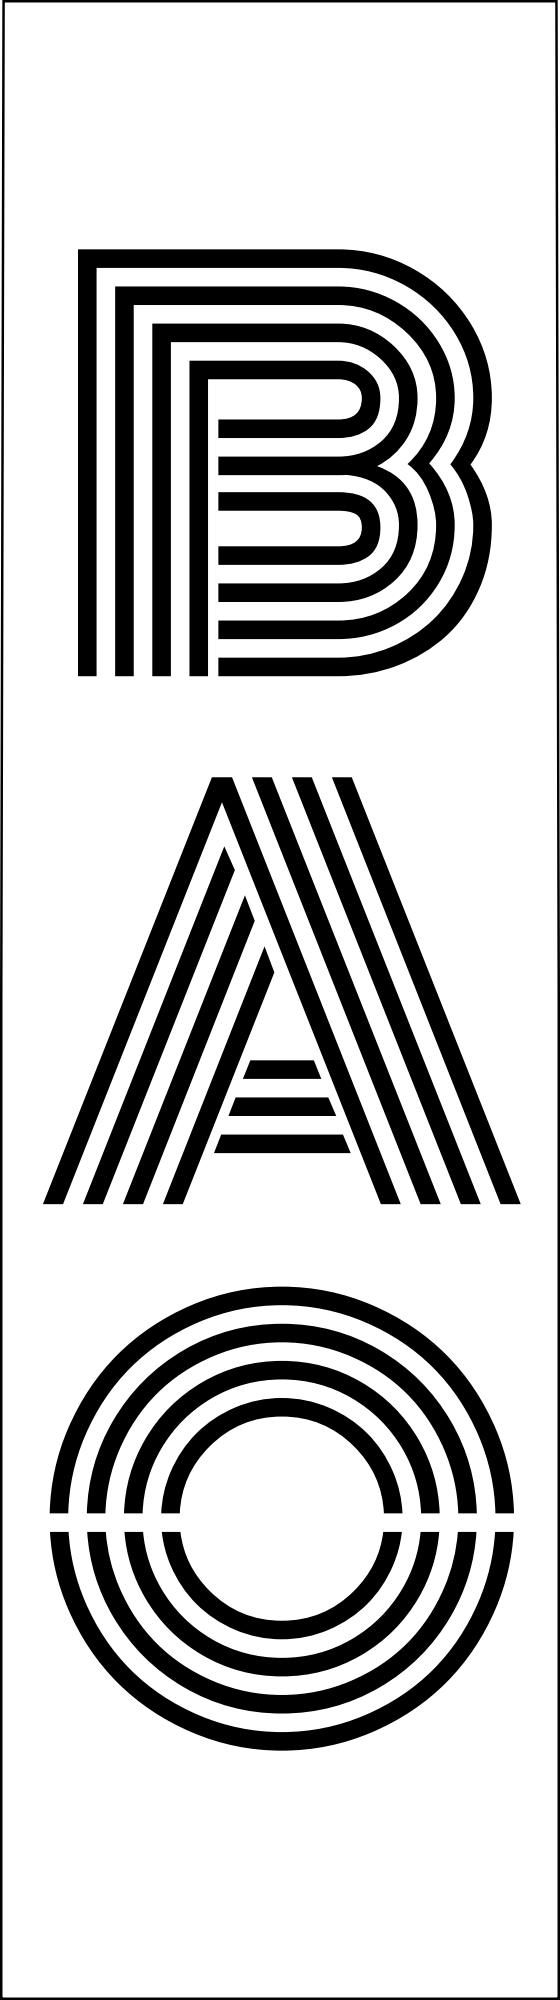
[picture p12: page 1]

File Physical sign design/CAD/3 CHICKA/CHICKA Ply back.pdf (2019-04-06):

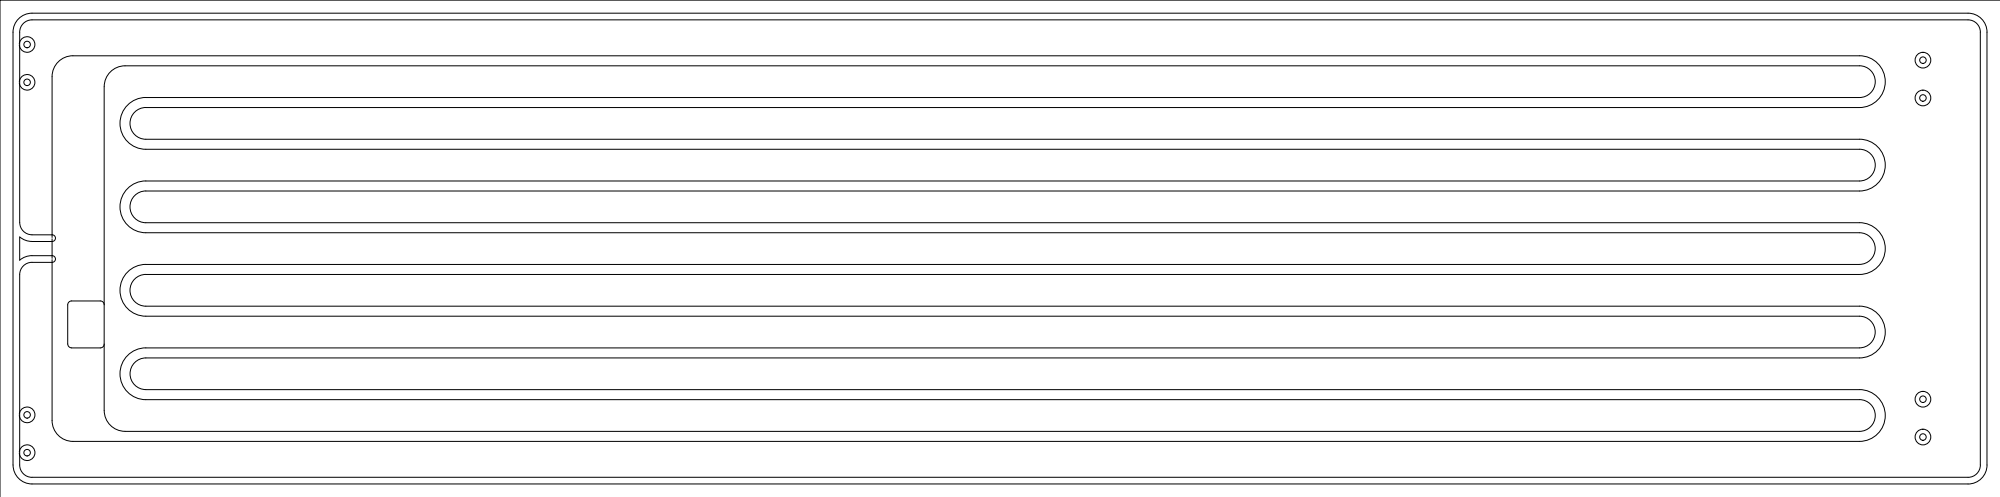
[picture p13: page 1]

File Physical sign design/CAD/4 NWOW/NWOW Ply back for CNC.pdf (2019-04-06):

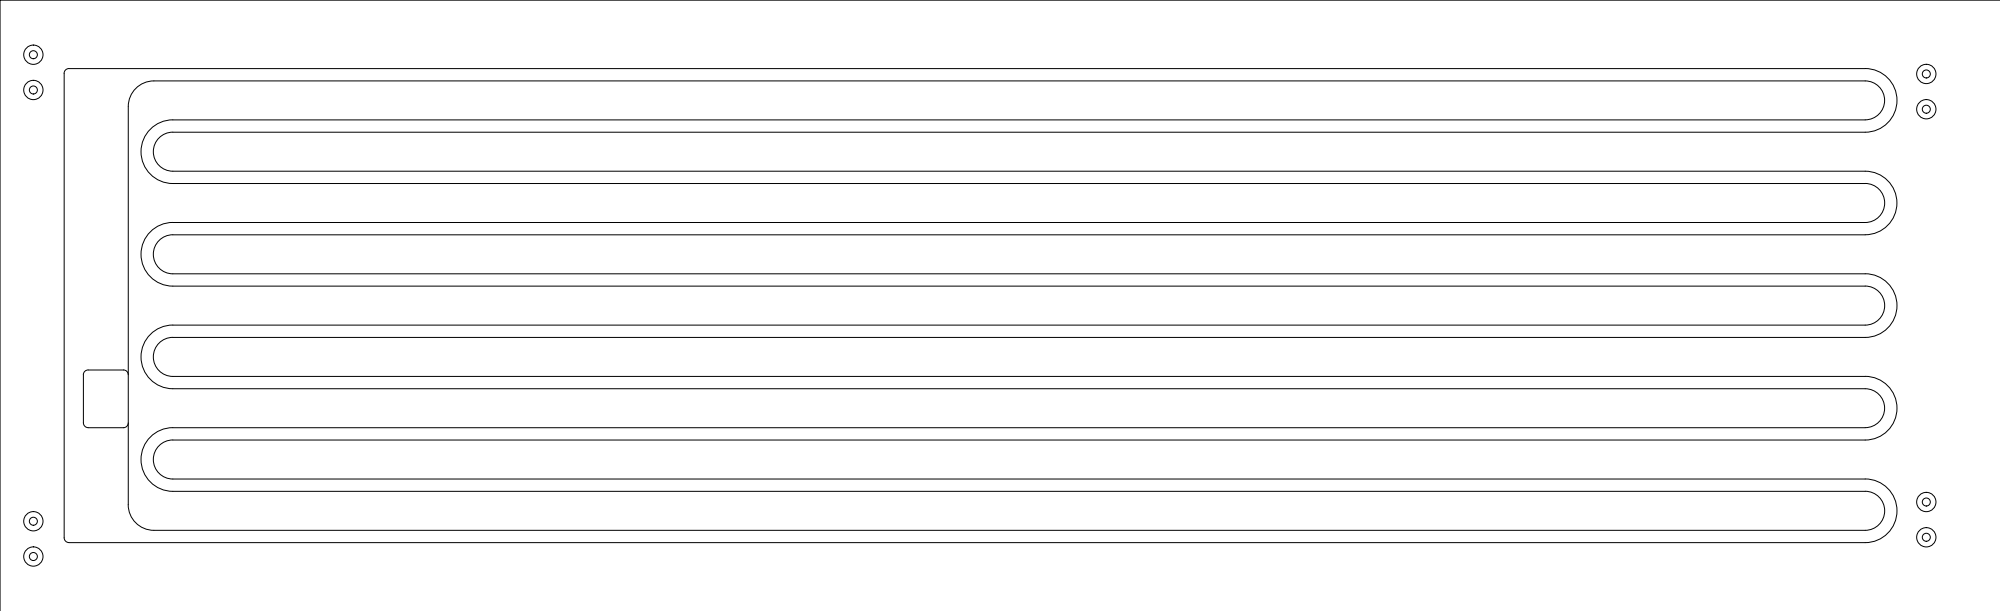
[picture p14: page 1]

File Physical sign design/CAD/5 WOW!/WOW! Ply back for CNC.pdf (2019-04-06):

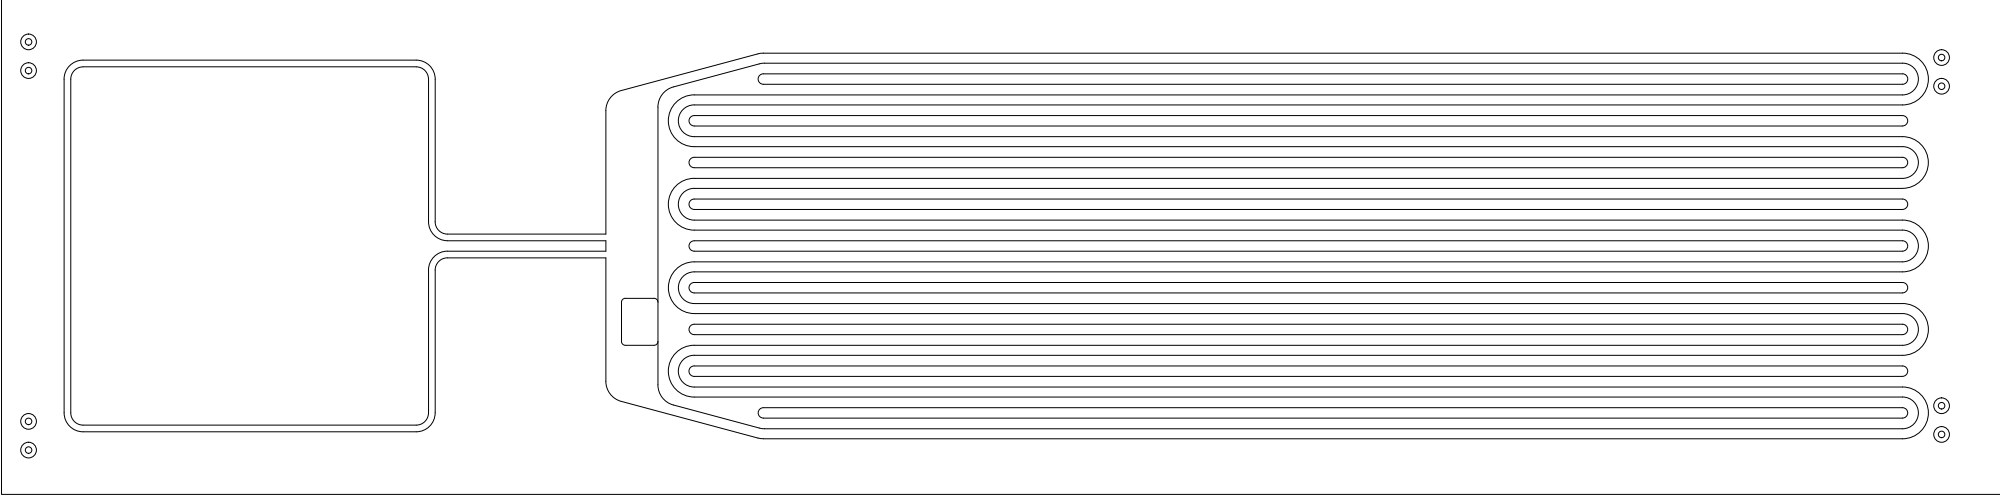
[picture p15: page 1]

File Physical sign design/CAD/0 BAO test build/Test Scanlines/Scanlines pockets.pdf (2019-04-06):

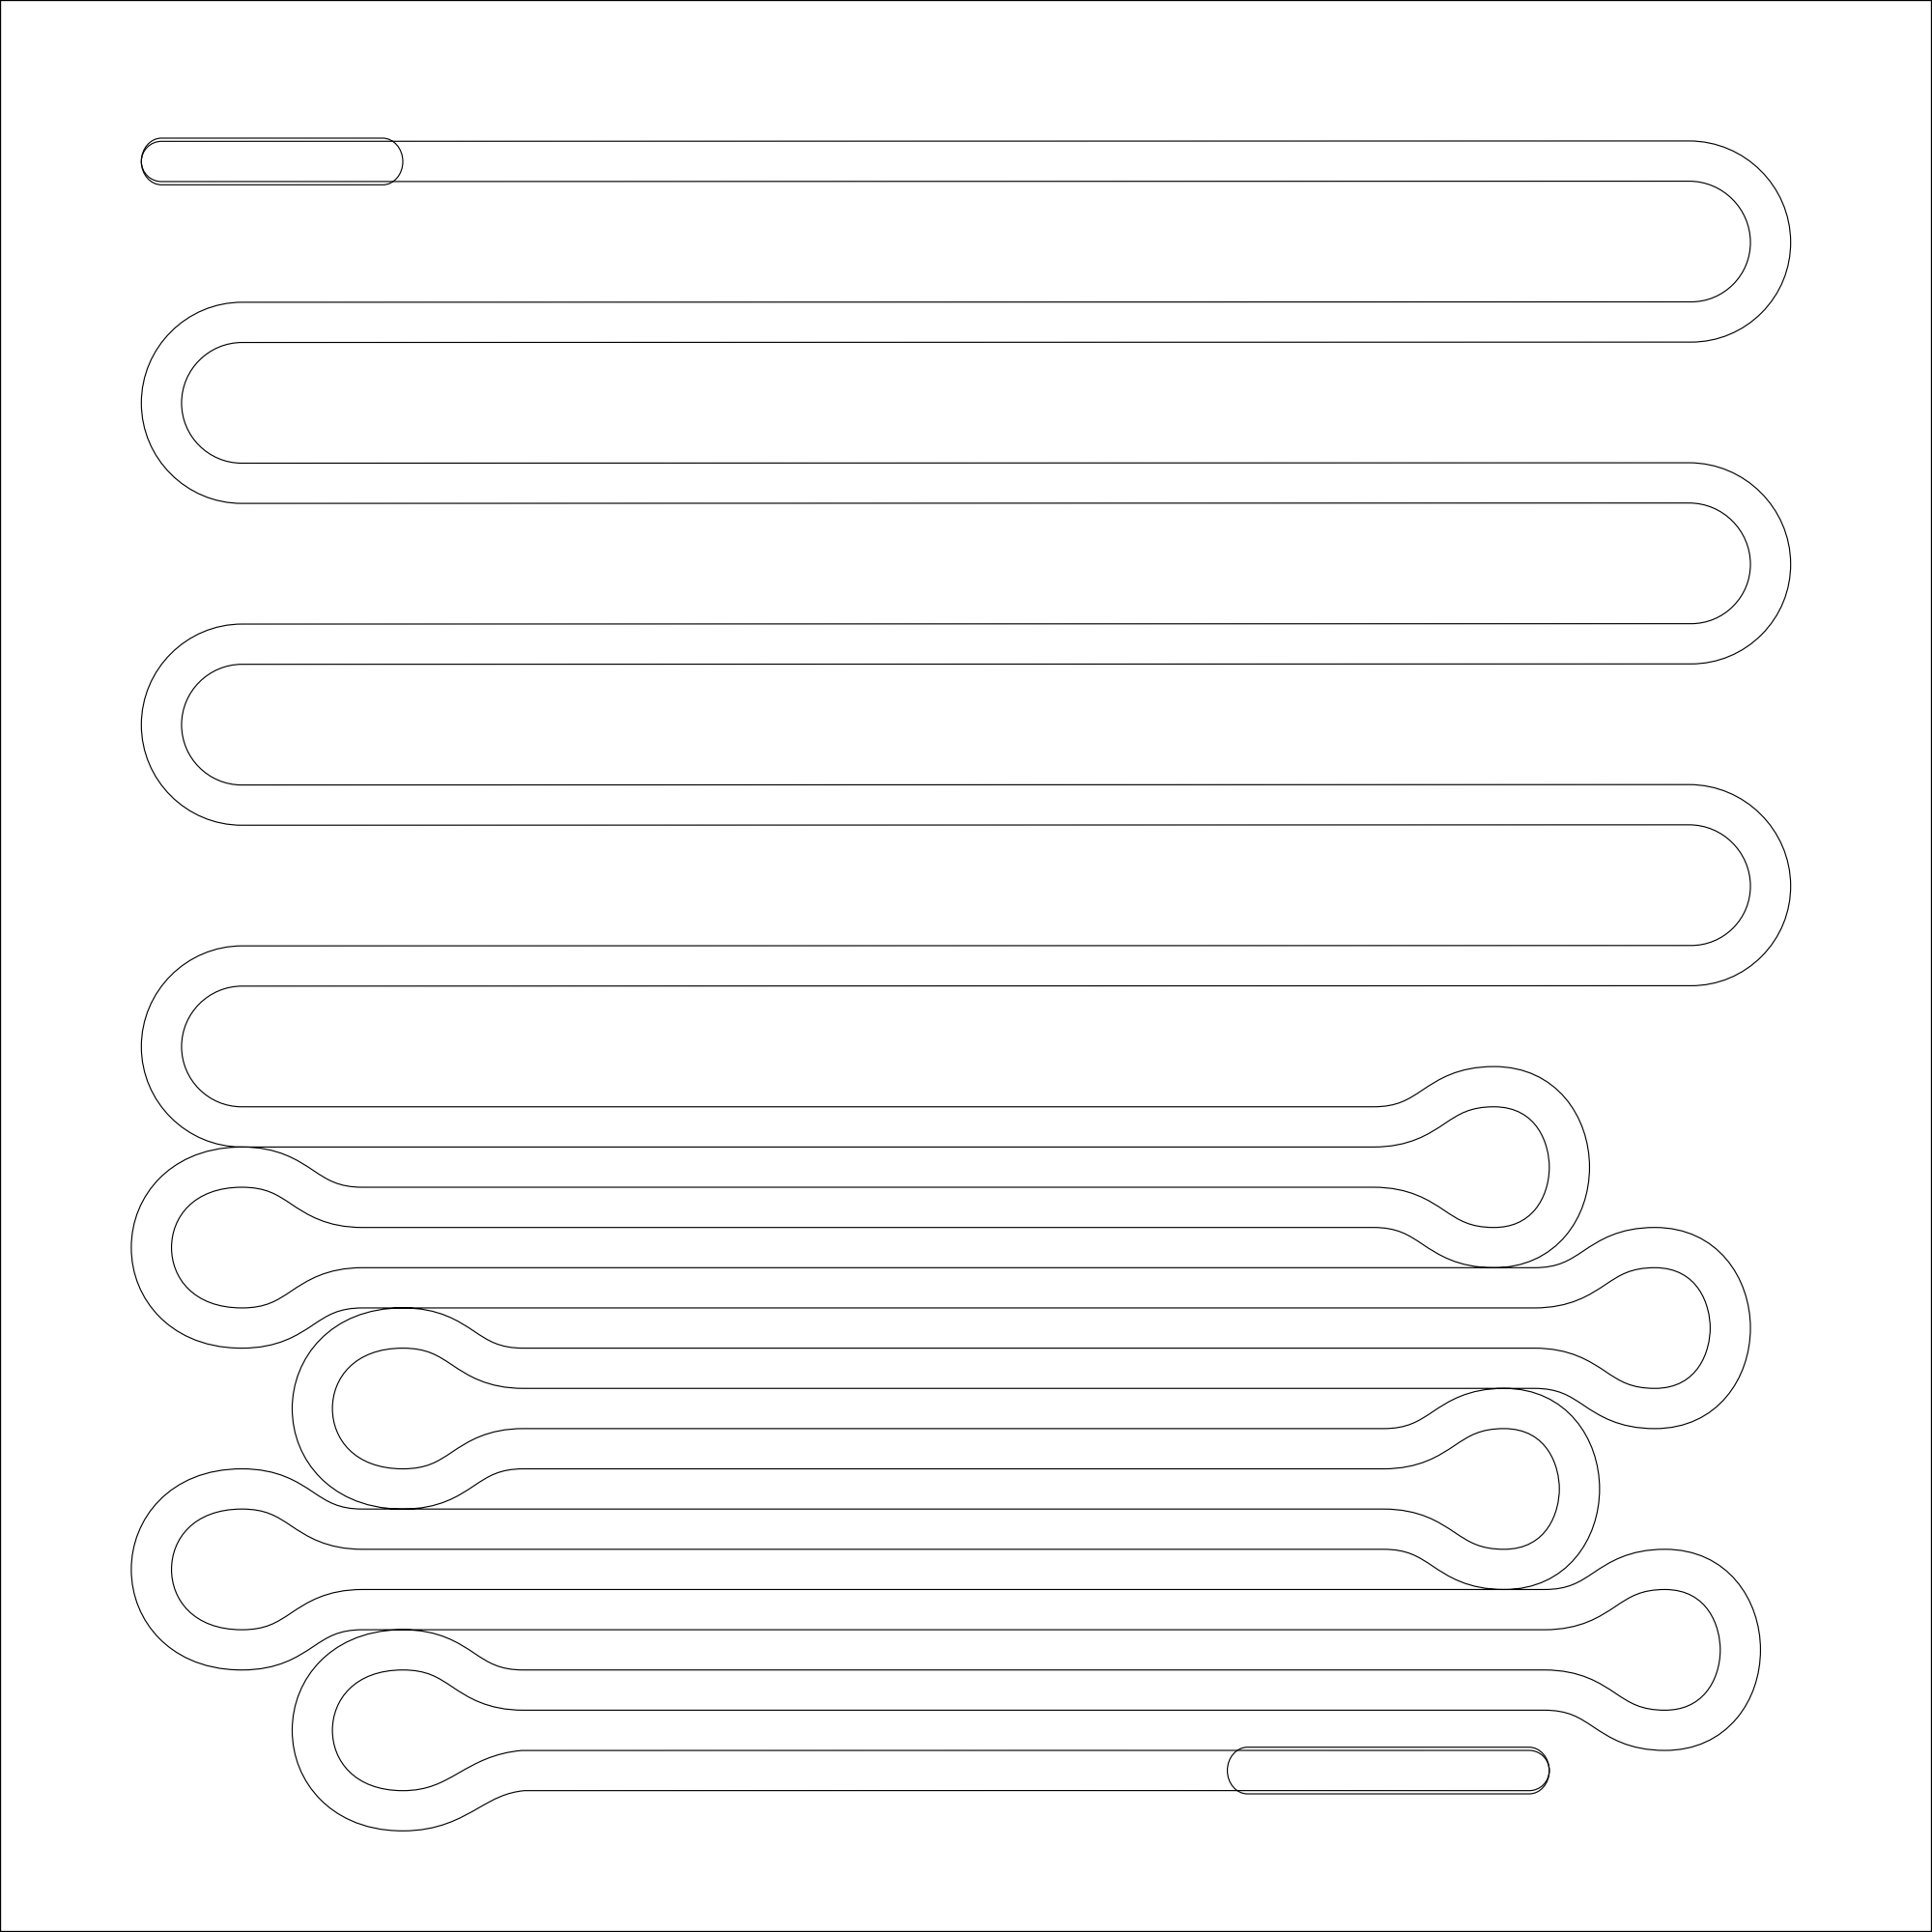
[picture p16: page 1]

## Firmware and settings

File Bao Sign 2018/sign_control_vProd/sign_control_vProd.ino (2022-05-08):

/*
  Bao Sign 2022

  Author: Jeff Vyduna
  Contact: web@jeffvyduna.com
  License: MIT

  Program Description: Blink 5 signs: HOT, BAO, CHICKA, [N|W]OW, WOW!

  10 position Ribbon/IDC cable pinout:
    PIN1 (red): GND
    PIN2      : GND
    PIN3      : Sign 1, HOT
    PIN4      : Sign 2, BAO
    PIN5      : Sign 3, CHICKA
    PIN6      : Sign 4, N/WOW
    PIN7      : Sign 5, WOW!
    PIN8      : Sign 4's Servo: Transform W to N
    PIN9      : VCC
    PIN10     : VCC

*/

#define DEBUG                   // Debugging print utilities. Takes a lot of memory. Comment this line for "production"
#include "DebugUtils.h"
#include "SignMessages.h"       // Defines symbols like _BCWW and BAO_CHICKA_WOW_WOW
#include <Servo.h>              // Servo PWM control.

// Hardware config
const byte firstRelayPin = 2;   // Relay for HOT; +1 = BAO, etc
const byte numRelays = 5;
const byte NWOW_IDX = 2;        // bit vector index of which sign in a HBCWWN vector is the swappable [N/W]OW sign
const byte servoPin = 7;
const byte baoNowModePin = 8;   // When low (using internal pullup), override normal mode to Serving BaoNow mode.
const int servoNPos = 40;       // Calibrate to the servo arm position when W is covered to show N
const int servoWPos = 140;      // Calibrate to the servo arm position when W uncovered to show W
const unsigned int servoDelay = 1000; // milliseconds to wait for flap to change position

// Global variables
boolean sign4isN = true;                 // True when we think it reads NOW, not WOW
Servo nwServo;

unsigned int bpm;
unsigned long beatPeriod;                // Tempo (BPM) = 1000/beatPeriod*60
unsigned int b1_2, b1_4, b3_4, b1_8, b1, b2, b4, b8;   // BeatPeriod */ factors
boolean baoNowMode;

void startupDiagnostic();
void setTempo(unsigned int _bpm);
void setAllOff();
void runBaoNowAnims();
void runRegularAnims();
void flickerOn(byte message);
void flickerOff(byte message);
void setMessage(byte message);
void setSign(int signIndex, boolean state);
void sign4toW();
void sign4toN();
void sign4toNSlow();
void on_off(byte message, int period);

// Setup arrays of functions so we can call a random function via random index
#define NUMBER_OF_ANIMATIONS 12           // highest animX() + 1
void (*animations[NUMBER_OF_ANIMATIONS])();
#define NUMBER_OF_BAONOW_ANIMATIONS 8    // highest baoNowAnimX() + 1
void (*baoNowAnimations[NUMBER_OF_BAONOW_ANIMATIONS])();
void anim0();
void anim1();
void anim2();
void anim3();
void anim4();
void anim5();
void anim6();
void anim7();
void anim8();
void anim9();
void anim10();
void anim11();
void baoNowAnim0();
void baoNowAnim1();
void baoNowAnim2();
void baoNowAnim3();
void baoNowAnim4();
void baoNowAnim5();
void baoNowAnim6();
void baoNowAnim7();
void baoNowAnim2helper1();
void baoNowAnim4helper();
void setupFunctions() {
  animations[0] = anim0;  animations[1] = anim1;  animations[2] = anim2;  animations[3] = anim3;
  animations[4] = anim4;  animations[5] = anim5;  animations[6] = anim6;  animations[7] = anim7;
  animations[8] = anim8;  animations[9] = anim9;  animations[10] = anim10; animations[11] = anim11;

baoNowAnimations[0] = baoNowAnim0;  baoNowAnimations[1] = baoNowAnim1;  baoNowAnimations[2] = baoNowAnim2;
baoNowAnimations[3] = baoNowAnim3;  baoNowAnimations[4] = baoNowAnim4;  baoNowAnimations[5] = baoNowAnim5;
baoNowAnimations[6] = baoNowAnim6;  baoNowAnimations[7] = baoNowAnim7;
}


void d(int ms) { delay(ms); }
void d1()   { delay(beatPeriod); }
void d1_2() { delay(b1_2); }
void d1_4() { delay(b1_4); }
void d3_4() { delay(b3_4); }
void d1_8() { delay(b1_8); }
void d2()   { delay(b2); }
void d4()   { delay(b4); }
void d8()   { delay(b8); }


/////////////////////////////////
//    Setup - called once on start-up
/////////////////////////////////

void setup() {
  #ifdef DEBUG
    Serial.begin(57600);  // For debug print statements over serial port
    for (int i = 0; i < 10; i++) {
      if (Serial) break;
      delay(1000);
    }
    Serial.println("BCWW Neon Sign v2.0");
  #endif

  for (int pin = firstRelayPin; pin < firstRelayPin + numRelays; pin++) {
    pinMode(pin, OUTPUT);
  }
  pinMode(baoNowModePin, INPUT_PULLUP);
  nwServo.attach(servoPin, 700, 2300);

  setupFunctions();
  setTempo(50);
  startupDiagnostic();
  randomSeed(analogRead(0));  // Different seed value each time
  DEBUG_PRINTLN("Setup complete\n");
}


/////////////////////////////////
//    Loop
/////////////////////////////////

void loop() {
  setTempo(50);
  if (digitalRead(baoNowModePin) == LOW) {
    DEBUG_PRINTLN("Manual BaoNow mode button detected.");
    runBaoNowAnims();
  } else {
    runRegularAnims();
  }
}

void runRegularAnims() {
  // Play a random animation, don't repeat until all have been used
  DEBUG_PRINTLN("Resetting used animations vector")
  unsigned long animsUsed = pow(2,NUMBER_OF_ANIMATIONS) - 1;
  while (animsUsed > 0) {
    if (digitalRead(baoNowModePin) == LOW) {
      DEBUG_PRINTLN("Stopping to switch to Bao Now mode.");
      return;
    }
    byte currentAnim = random(NUMBER_OF_ANIMATIONS);
    if (bitRead(animsUsed,currentAnim)) {
      #ifdef DEBUG
        Serial.print("Remaining Regular animation vector: ");
        Serial.println(animsUsed, BIN);
        Serial.print("Starting Regular anim: ");
        Serial.println(currentAnim);
      #endif
      animations[currentAnim]();
      bitClear(animsUsed,currentAnim);
    }
  }
}


void runBaoNowAnims() {
  // Play a random animation, don't repeat until all have been used
  DEBUG_PRINTLN("Resetting used BaoNow animations vector")
  unsigned long BNAnimsUsed = pow(2,NUMBER_OF_BAONOW_ANIMATIONS) - 1;
  while (BNAnimsUsed > 0) {
    if (digitalRead(baoNowModePin) != LOW) {
      DEBUG_PRINTLN("Stopping to switch to Regular mode.");
      return;
    }
    byte currentAnim = random(NUMBER_OF_BAONOW_ANIMATIONS);
    if (bitRead(BNAnimsUsed,currentAnim)) { // Prevent random repeats until all consumed
      #ifdef DEBUG
        Serial.print("Remaining BaoNow animation vector: ");
        Serial.println(BNAnimsUsed, BIN);
        Serial.print("Starting BaoNow anim: ");
        Serial.println(currentAnim);
      #endif
      baoNowAnimations[currentAnim]();
      bitClear(BNAnimsUsed,currentAnim);
    }
  }
}

/////////////////////////////////
//    Animations
/////////////////////////////////

void anim0() {  // Flicker on, On for 4 beats, flicker off
  setAllOff(); d4();
  flickerOn(_BCWW);
  d4();
  flickerOff(_BCWW); d4();
}

void flickerOn(byte message) {
  for (int i=0; i<6; i++) { // Flicker on
    setMessage(message); d(20+random(50));
    setAllOff(); d(random(200/(i+1)));
  }
  setMessage(message);
}
void flickerOff(byte message) {
  for (int i=0; i<4; i++) { // Flicker off
    setMessage(message); d(random(200/(i+1)));
    setAllOff(); d(random(100*(i+1)));
  }
}


void anim1() {  // On for 16s
  setAllOff();
  d4();
  setMessage(_BCWW);
  d(16000);
}
void anim2() {  // Slow blink
  for (int i=0; i<6; i++) {
    setMessage(_BCWW);
    d2();
    setAllOff();
    d2();
  }
}
void anim3() { // Slow sequence with space
  for (int i=0; i<3; i++) {
    setMessage(_B___); d1();
    setMessage(__C__); d1();
    setMessage(___W_); d1();
    setMessage(____W); d1();
  }
}
void anim4() { // Med sequence with space
  for (int i=0; i<3; i++) {
    setMessage(_B___); d1_2(); setAllOff(); d1_2();
    setMessage(__C__); d1_2(); setAllOff(); d1_2();
    setMessage(___W_); d1_2(); setAllOff(); d1_2();
    setMessage(____W); d1_2(); setAllOff(); d1_2();
  }
}
void anim5() { // Medium build
  for (int i=0; i<4; i++) {
    setMessage(_B___); d1_2();
    setMessage(_BC__); d1_2();
    setMessage(_BCW_); d1_2();
    setMessage(_BCWW); d1_2();
  }
}
void anim6() {
  int _bpm = bpm;
  for (int i=0; i<random(8); i++) {
    setTempo(100 + random(250));
    anim5();
    d(random(2000));
    anim3();
    d(random(2000));
    anim4();
    d(random(2000));
  }
  setTempo(_bpm);
}
void anim7() {
  int _bpm = bpm;
  for (int i=0; i<4+random(32); i++) {
    setTempo(100 + random(60));
    for (int j=0; j<8+random(8); j++) {
      switch(random(4)) {
        case 0: setMessage(_B___); break;
        case 1: setMessage(__C__); break;
        case 2: setMessage(___W_); break;
        case 3: setMessage(____W); break;
      }
      d1_4();
    }
  }
  setTempo(_bpm);
}
// Flip randomly
void anim8() {
  boolean states[numRelays] = { 0, };
  for (int i=0; i<30+random(30); i++) {
    byte pinToFlip = firstRelayPin + random(4);
    states[pinToFlip] = !states[pinToFlip];
    digitalWrite(pinToFlip, states[pinToFlip]);
    d(50 + random(500));
  }
}

void anim9() { // Chase with increasing temp, then backwards
  for (int i=0; i<1000; i+=9) {
    switch(i%4) {
      case 0: setMessage(_B___); break;
      case 1: setMessage(__C__); break;
      case 2: setMessage(___W_); break;
      case 3: setMessage(____W); break;
    }
    d(200*(cos(2*PI*i/1000)+1)/2);
  }
  d1();
  for (int i=0; i<1000; i+=9) {
    switch(i%4) {
      case 0: setMessage(____W); break;
      case 1: setMessage(___W_); break;
      case 2: setMessage(__C__); break;
      case 3: setMessage(_B___); break;
    }
    d(200*(cos(2*PI*i/1000)+1)/2);
  }
}
void anim10() { // Bao Bao..... chicka chicakaaahhhhh
  d4();
  setTempo(130);
  setMessage(_B___); d1_2(); setAllOff(); d1_2();
  setMessage(_B___); d1_2(); setAllOff(); d1_2();
  d2(); d4(); d8();
  setMessage(_B___); d1_2(); setAllOff(); d1_4();
  setMessage(_B___); d1_2(); setAllOff(); d1_4();
  d2(); d4(); d4(); d2(); d1_2();
  setMessage(__C__); d1_4(); setAllOff(); d1_4();
  setMessage(__C__); d1();
  setMessage(_B___); d1_2(); setAllOff(); d1_2();
  setMessage(_B___); d1_2(); setAllOff(); d1_2();
  d4();
}

void anim11() { // FlickerCandy
  d4();

  for (int i=0; i<7; i++) {
    setMessage(BAO); d(20+random(100*i+1));
    setAllOff(); d(random(50+300/(i+1)));
  }
  setMessage(BAO); d(2000);

  for (int i=0; i<7; i++) {
    setMessage(BAO); d(20+random(100));
    setAllOff(); d(random(50+200/(i+1)));
    setMessage(CHICKA); d(20+random(100));
  }
  setMessage(CHICKA); d(1200);

  for (int i=0; i<11; i++) {
    setMessage(CHICKA); d(20+random(100));
    setAllOff(); d(random(100));
    setMessage(WOW1); d(20+random(100));
    setAllOff(); d(random(75));
  }
  setMessage(WOW1); d(900);

  for (int i=0; i<17; i++) {
    setMessage(WOW1); d(20+random(200));
    setAllOff(); d(random(100));
    setMessage(WOW2); d(20+random(1+i*5));
    setAllOff(); d(random(75));
  }
  setMessage(WOW2); d(3000);

  setAllOff();
}



void baoNowStart() { //  Initial transition to BAO NOW mode
  DEBUG_PRINTLN("Starting BaoNow mode");
  setTempo(50);
  setAllOff(); d(4);
  setMessage(BAO_WOW); d(2);
  sign4toNSlow();
  for (int i=0; i<16; i++) {
    setMessage(HOT_BAO_NOW); d(100);
    setAllOff(); d(100);
  }
  const byte HBN[3] = {HOT, BAO, NOW};
  for (int i=0; i<18; i++) {
    setMessage(HBN[i%3]); d(100);
  }
  setAllOff(); d1();
  for (int i=1; i<=1024; i*=2) {
    setMessage(HOT_BAO_NOW); d(i);
    setAllOff(); d(1025-i);
  }
  setAllOff(); d1();
  setMessage(NOW); d2();
  setAllOff(); d1();
}

void baoNowAnim0() { // HOT + BAO + NOW
  for (int delayBase = 32; delayBase>=4; delayBase/=2) {
    setMessage(HOT); d(delayBase*100);
    setMessage(HOT_BAO); d(delayBase*100);
    setMessage(HOT_BAO_NOW); d(delayBase*100);
    setAllOff(); d(delayBase*50);
    setMessage(WOW2); d(delayBase*25);
    setAllOff(); d(delayBase*25);
  }
  d4();
}
void baoNowAnim1() { // HOT BAO, HOT NOW, WOW!
  setTempo(100);
  setAllOff(); d1();
  for (int i=0; i<4; i++) {
    setMessage(HOT_BAO); d1(); d1_4();
    setAllOff(); d1_8();
    setMessage(HOT_NOW); d1();
    setAllOff(); d1_4();
    setMessage(WOW2); d1_8();
    setAllOff(); d1_4(); d1_2();
  }
}

void baoNowAnim2() { // BAO, HOT, NOW, WOW!
  int _bpm = bpm;
  setAllOff(); d1();
  for (int i=0; i<4; i++) {
    setTempo(80+40*i);
    baoNowAnim2helper1();
  }
  for (int i=0; i<6; i++) {
    setMessage(HOT_BAO_NOW_WOW); d1_2();
    setAllOff(); d1_2();
  }
  for (int i=0; i<3; i++) {
    setMessage(HOT_BAO_NOW_WOW); d1_4();
    setAllOff(); d1_4();
  } d1_2();
  d4(); d4();
  setMessage(WOW2); d1_2(); setAllOff();
  d4();d4();
  setTempo(_bpm);
}
void baoNowAnim2helper1() { // BAO, HOT, NOW, WOW!
  for (int i=0; i<2; i++) {
    setMessage(BAO); d1();
    setAllOff(); d1_2();
    setMessage(HOT); d1_2();
    setMessage(NOW); d1_2();
    setAllOff();  d1_2();
    setMessage(WOW2); d1_2();
    setAllOff();  d1_2();
  }
}

void baoNowAnim3() { // Flicker BAO <wait> Flicker HOT NOW...
  int _bpm = bpm;
  setTempo(50);
  setAllOff(); d4();
  flickerOn(BAO); flickerOn(BAO);
  flickerOff(BAO);
  d2();
  flickerOn(HOT_NOW);
  d1();
  flickerOff(HOT_NOW);
  setTempo(_bpm);
}

void baoNowAnim4() { // HOT CHICKA BAO BAO, HOT CHICKA BAO <pause>
  int _bpm = bpm;
  setTempo(50);
  baoNowAnim4helper();
  setTempo(100);
  baoNowAnim4helper();
  setTempo(200);
  baoNowAnim4helper();
  setTempo(_bpm);
}
void baoNowAnim4helper() {
  for (int i=0; i<2; i++) {
    on_off(HOT, b1_2);
    on_off(CHICKA, b1_2);
    on_off(BAO, b1_2);
    on_off(BAO, b1_2);
    on_off(HOT, b1_2);
    on_off(CHICKA, b1_2);
    on_off(BAO, b1_2);
    d1_2();
  }
}
void on_off(byte message, int period) {
  setMessage(message); d(period/2);
  setAllOff(); d(period/2);
}

void baoNowAnim5() { // Freestyle MC. A Rap.
  d4();
  int _bpm = bpm;
  setTempo(90);

  on_off(HOT, b1_2);
  on_off(CHICKA, b1_2);
  on_off(CHICKA, b1_2);
  on_off(BAO, b1_2);
  on_off(BAO, b1_2);
  d1(); d1_2();

  on_off(BAO, b1_2);
  on_off(CHICKA, b1_2);
  on_off(CHICKA, b1_2);
  on_off(BAO, b1_2);
  on_off(WOW2, b1_2);
  d1(); d1_2();

  on_off(HOT, b1_2);
  on_off(CHICKA, b1_2);
  on_off(CHICKA, b1_2);
  on_off(BAO, b1_2);
  on_off(NOW, b1_2);
  d1(); d1_2();

  on_off(HOT, b1_2);
  on_off(BAO, b1_2);
  on_off(HOT, b1_2);
  on_off(NOW, b1_2);
  on_off(WOW2, b1_2);
  d1(); d1_2();

  on_off(BAO, b1_2);
  on_off(WOW2, b1_2);
  on_off(CHICKA, b1_2);
  on_off(BAO, b1_2);
  on_off(CHICKA, b1_2);
  on_off(BAO, b1_2);
  on_off(WOW2, b1_2);
  d1_2();

  on_off(NOW, b1_2);
  on_off(BAO, b1_2);
  on_off(HOT, b1_2);
  on_off(BAO, b1_2);
  on_off(CHICKA, b1_2);
  on_off(BAO, b1_2);
  on_off(WOW2, b1_2);
  d1_2();

  on_off(NOW, b1_2);
  on_off(BAO, b1_2);
  on_off(HOT, b1_2);
  on_off(BAO, b1_2);
  on_off(CHICKA, b1_2);
  on_off(BAO, b1_2);
  on_off(NOW, b1_2);
  d1_2();

  on_off(BAO, b1);
  on_off(CHICKA, b1);
  on_off(NOW, b1);
  on_off(WOW2, b1);

  on_off(BAO, b1_2);
  on_off(CHICKA, b1_2);
  on_off(CHICKA, b1_2);
  on_off(BAO, b1_2);
  on_off(BAO, b1_2);
  on_off(CHICKA, b1_2);
  on_off(CHICKA, b1_2);
  on_off(BAO, b1_2);
  on_off(BAO, b1_2);
  on_off(CHICKA, b1_2);
  on_off(NOW, b1_2);
  on_off(BAO, b1_2);
  on_off(HOT_NOW, b1);
  on_off(HOT_NOW, b1);


  setTempo(_bpm);
}

void baoNowAnim6() { // HOT NOW / WOW flickers
  d4();
  flickerOn(HB_N_); d2();
  flickerOn(HB_W_); d2();
  sign4toN(); d2();
  sign4toW(); d2();
  sign4toN(); d2();
  sign4toW(); d2();
  sign4toNSlow(); d4();
  sign4toW(); d2();
  flickerOn(H__W_); d2();
  sign4toNSlow(); d4();
  flickerOff(H__N_);
  setAllOff();
  sign4toW(); d2();
  flickerOn(_B_WW); d2();
  sign4toNSlow(); d1();
  flickerOff(_B_NW); d2();
  flickerOff(_B_NW); flickerOff(_B_NW); flickerOn(_B_NW); d1(); flickerOff(_B_NW);
  d4();
}


void baoNowAnim7() { // Flickers
  int _bpm = bpm;
  setTempo(50);
  setAllOff(); d4();
  flickerOn(HOT); flickerOn(HOT); d1(); flickerOn(HOT); flickerOff(HOT); d1();
  flickerOn(BAO); flickerOn(BAO); flickerOff(BAO); flickerOn(HOT); flickerOn(BAO); flickerOff(HOT); d1_2(); flickerOff(BAO); d1();
  flickerOn(BAO); flickerOn(NOW); d1_4(); flickerOff(BAO); flickerOn(NOW); flickerOff(BAO); flickerOn(NOW); d1(); flickerOff(NOW); d2();

  setTempo(_bpm);
}



////////////////////////////////////////////////
//    Utility functons used by the animations
///////////////////////////////////////////////

/* Takes a symbol that is a binary vector representation of the state of the 5 signs
     folowwed by the LSB that signifies if sign 4's realy should be in the "N" ("NOW") position
     So, "___ BAO CHICKA WOW WOW" = BCWW = B011110
*/
void setMessage(byte message) {
  // Only think about swapping sign4's position if it's going to be illuminated
  if (bitRead(message, NWOW_IDX)) {
    if (bitRead(message, 0)) sign4toN();
    else sign4toW();
  }
  #ifdef DEBUG
  // Serial.print("SetMessage: "); Serial.println(message,BIN);
  #endif

  message >>= 1; // Get ast N/W bit and into the on/off bits

  for (byte i = 0; i < numRelays; i++) {
    setSign(numRelays-1-i, bitRead(message >> i,0));
  }
}


// Doesn't check for servo state before turning off all lights in signs
void setAllOff() {
  for (int i = 0; i < numRelays; i++) {
    setSign(i, 0);
  }
}


// signIndex 0 is HOT, 4 is WOW!
void setSign(int signIndex, boolean state) {
  if (signIndex > numRelays) return;  // bounds checking

  // Pin high means relay interrupts the AC line voltage, turning off that rope light
  digitalWrite(firstRelayPin + signIndex, !state);
}

void sign4toW() {
  if (sign4isN) {
    nwServo.write(servoWPos);
    d(servoDelay);
    sign4isN = 0;
  }
}

void sign4toN() {
  if (!sign4isN) {
    nwServo.write(servoNPos);
    d(servoDelay);
    sign4isN = 1;
  }
}

void sign4toNSlow() {
  sign4toW();
  for (int t=0; t<3000; t++) {
    int pos = servoWPos + (servoNPos-servoWPos)*t/3000;
    nwServo.write(pos); d(1);
  }
  nwServo.write(servoNPos);
  sign4isN = 1;
}


///////////////////////////////
// Time, Delay, Speed Utilities
///////////////////////////////


void startupDiagnostic() {
  setMessage(H____); d1();
  setMessage(_B___); d1();
  setMessage(__C__); d1();
  setMessage(___W_); d1();
  setMessage(___N_); d1();
  setMessage(____W); d1();
  setMessage(_BCWW); d1();
  setAllOff();
}


void setTempo(unsigned int _bpm) {
  bpm = _bpm;
  beatPeriod = 1000 * 60 / _bpm;
  #ifdef DEBUG
//  Serial.print("\nBPM:" + String(_bpm) + "  Period: " + String(beatPeriod));
  #endif
  b1   = beatPeriod;
  b1_2 = beatPeriod/2;
  b1_4 = beatPeriod/4;
  b3_4 = beatPeriod*4/4;
  b1_8 = beatPeriod/8;
  b2   = beatPeriod*2;
  b4   = beatPeriod*4;
  b8   = beatPeriod*8;
}

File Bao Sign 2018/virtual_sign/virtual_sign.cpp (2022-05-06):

#include <unistd.h>
#include <sys/stat.h>

#include "virtual_sign.h"

boolean dirty;
boolean HOT = 0;
boolean BAO = 0;
boolean CHICKA = 0;
boolean NWOW = 0;
boolean WOW = 0;
char NW = '?';

Ser Serial;

void Ser::begin(int baud) {
}

void Ser::print(int i) {
  fprintf(stderr, "%d", i);
}

void Ser::println(int i) {
  fprintf(stderr, "%d\n", i);
}

void Ser::print(const char *s) {
  fprintf(stderr, "%s", s);
}

void Ser::println(const char *s) {
  fprintf(stderr, "%s\r\n", s);
}

void Ser::println(int n, int bin) {
  if (bin != BIN) {
    fprintf(stderr, "Weird print call\n");
  } else {
    for (int i = 0; i < 12; i++) {
      fprintf(stderr, "%c", (n & 2048 >> i) ? '1' : '0');
    }
    fprintf(stderr, "\n");
  }
}

Servo::Servo(void) {

}

void Servo::attach(int pin, int i1, int i2) {

}

void Servo::write(int i) {
  if (i == 40) NW = 'N';
  else if (i == 140) NW = 'W';
  else NW = 'X';
  dirty = 1;
}

uint32_t random(uint32_t maxPlusOne) {
  return rand() % maxPlusOne;
}


inline bool file_exists (const char * name) {
  struct stat buffer;   
  return (stat (name, &buffer) == 0); 
}

int digitalRead(int pin) {
  switch(pin) {
    case 8:
      return !file_exists("/tmp/bao.touch");
    default:
      printf("Unknown pin %d\r\n", pin);
      while(1);
  }
}

void digitalWrite(int pin, int value) {
  value = !value;  // Caller sets to nonzero to pull low
  if (pin == 2) HOT = value;
  else if (pin == 3) BAO = value;
  else if (pin == 4) CHICKA = value;
  else if (pin == 5) NWOW = value;
  else if (pin == 6) WOW = value;
  else {
    fprintf(stderr, "Unknown pin %d\r\n", pin);
    while(1);
  }
  dirty = 1;
}

double analogRead(int pin) {
  return 0.0;
}

void set_color(boolean on) {
  if (on) {
    printf("\e[91m");
  } else {
    printf("\e[90m");
  } 
}

void print_sign() {
  char nwow[4] = { '_', 'O', 'W', '\0' };
  nwow[0] = NW;

  printf("\033[F");  // Return to start of previous line
  set_color(HOT); printf("HOT ");
  set_color(BAO); printf("BAO ");
  set_color(CHICKA); printf("CHICKA ");
  set_color(NWOW); printf("%s ", nwow);
  set_color(WOW); printf("WOW!");
  printf("\e[0m\n"); 
  dirty = 0;
}

void delay(int msec) {
  if (dirty) print_sign();
  usleep(msec * 1000);
}

void setup();
void loop();
int main(int argc, char **argv) {
  dirty = 1;
  printf("\n");
  setup();
  while (1) {
    loop();
    delay(0);
  }
}

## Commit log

2019-04-06 Update README.md
    Now/Wow servo and ribbon connections
2019-04-20 Correct animation array assignment
    [sign_control_vProd.ino]
2022-05-06 Added simulator, removed RTC, and fixed an uncountable number of div0 errors
    [sign_control_vProd.ino, virtual_sign.cpp]
2022-05-07 Completely move to N at end of slow-servo function
